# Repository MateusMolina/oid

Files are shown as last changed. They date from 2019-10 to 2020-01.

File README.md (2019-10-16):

# OID | Órteses Inteligentemente Desenvolvidas

Temos o propósito de divulgar de forma open source novos projetos e planos de fabricação de órteses, com foco na qualidade e no custo baixo de fabricação.

## Nossos Projetos

### OID para PTC

- Modelo de órtese
- Tese de bacharelado com roteiro de fabricação

## Membros

- Sérgio Fernando Lajarin
- Mateus Molina

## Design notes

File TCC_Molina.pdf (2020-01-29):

## UNIVERSIDADE FEDERAL DO PARANÁ

SETOR DE TECNOLOGIA

DEPARTAMENTO DE ENGENHARIA MECÂNICA

(DEMEC)

MATEUS MOLINA

ESTUDO COMPARATIVO ENTRE A MANUFATURA ADITIVA E A TERMOFORMAGEM NA FABRICAÇÃO DE ÓRTESES PARA

CRIANÇAS COM PTC

CURITIBA
2019

MATEUS MOLINA

ESTUDO COMPARATIVO ENTRE A MANUFATURA ADITIVA E A TERMOFORMAGEM NA FABRICAÇÃO DE ÓRTESES PARA

CRIANÇAS COM PTC

Monografia apresentada como resultado parcial

à obtenção do grau de engenheiro mecânico,

Curso de Engenharia Mecânica, Setor de

Tecnologia, Universidade Federal do Paraná.

Orientador: Prof. Sérgio Fernando Lajarin

CURITIBA
2019

RESUMO

O pé torto congênito é uma deformidade congênita com incidência de um caso a cada mil nascimentos, a qual é tratada, comumente, de modo não cirúrgico pela utilização de órteses. Ainda não há uma órtese acessível e de qualidade no mercado, o que cria uma oportunidade de estudo para um produto de baixo custo e que, ainda assim, mantenha-se durável e de boa qualidade ao longo da sua vida-útil. Este trabalho busca elucidar as diferenças em custo e parâmetros de qualidade entre órteses fabricadas por meio de dois processos de manufatura, manufatura aditiva e termoformagem com moldes impressos. Produziu-se, para tanto, amostras representativas para cada um dos processos, as quais, posteriormente, foram submetidas a um processo padronizado de teste e obtenção de resultados. Em consideração aos resultados, a termoformagem utilizando PS como material, apresentou melhores resultados em custo de fabricação para o período e estrutura de fabricação definidos, sem deixar de lado os parâmetros de qualidade.

Palavras-chave: Órtese, PTC, Tecnologia Assistiva, Manufatura Aditiva, Termoformagem

LISTA DE ILUSTRAÇÕES

FIGURA 2 - ÓRTESE PARA PTC EM CÓDIGO ABERTO FEITA EM PLA POR IMPRESSÃO

FIGURA 3 - ÓRTESE PRODUZIDA POR AM PARA PACIENTES COM PTC RESIDUAL .... 14

FIGURA 4 – EVOLUÇÃO DO TRATATAMENTO DE PTC NA FASE DE CORREÇÃO COM

FIGURA 10 – REPRESENTAÇÃO ESQUEMÁTICA DE UMA ÚNICA CADEIA POLIMÉRICA

FIGURA 12 - GRÁFICO DO VOLUME ESPECÍFICO EM FUNÇÃO DA TEMPERATURA

PARA TRÊS POLÍMEROS: A (CRISTALINO); B (SEMICRISTALINO); E C (AMORFO) ...... 25

FIGURA 17 - MECANISMO DE EXTRUSÃO GENÉRICO DE UMA IMPRESSORA 3D ........ 34

FIGURA 18 - ESQUEMÁTICO DE UMA PEÇA SENDO IMPRESSA EM 3D CAMADA POR

FIGURA 19 - IMPORTÂNCIA DA ORIENTAÇÃO NA RESISTÊNCIA DA PEÇA IMPRESSA 36

FIGURA 23 - PEÇA DE ABS DEPOIS DE SER TRATADA COM ACETONA (À ESQUERDA)

FIGURA 38 – BASES EM PLA NA ORIENTAÇÃO VERTICAL E HORIZONTAL (À DIREITA)

FIGURA 39 – EQUIPAMENTOS PARA ALISAMENTO SUPERFICIAL COM VAPOR DE

FIGURA 40 – BASE ORIENTAÇÃO VERTICAL EM ABS DEPOIS DO ACABAMENTO ....... 62

FIGURA 42 - MÁQUINA TERMOFORMADORA UTILIZADA PARA A FABRICAÇÃO DA

FIGURA 44 - PLACA E MOLDE POSICIONADOS NA MÁQUINA TERMOFORMADORA .... 67

FIGURA 46 - BASE DA ÓRTESE EM PS RECÉM-RETIRADA DA MÁQUINA

FIGURA 47 - BASE DA ÓRTESE FABRICADA COM EXCESSO DE EMBARRIGAMENTO. 69

FIGURA 48 – MÁQUINA UNIVERSAL DE ENSAIO E POSICIONAMENTO DA ÓRTESE (À

FIGURA 54 – DETALHE DAS MARCAS DE IMPRESSÃO DE UMA BASE IMPRESSA COM

LISTA DE TABELAS

TABELA 6 - FATOR DE AUMENTO RECOMENDADO DO MOLDE PARA DIFERENTES

CONTEÚDO

2.4.3. PLANEJAMENTO DE PROCESSO PARA MANUFATURA ADITIVA........ 37

### 1. INTRODUÇÃO

### 1.1. CONTEXTUALIZAÇÃO

Defeitos e deformidades congênitas são termos usados para descrever os

múltiplos defeitos ósseos e musculares que podem ocorrer durante a gestação. São

geralmente de origem complexa e, em alguns casos, de difícil detecção.

Estima-se que cerca de 2% a 3% dos recém-nascidos são portadores de

alguma deformidade congênita, sendo isso responsável por 20% da mortalidade

neonatal e 30% a 50% da mortalidade perinatal em países desenvolvidos. (CASTRO

et al., 2006)

Dentre as deformidades, o pé torto congênito é uma deformidade congênita

complexa causada pelo desenvolvimento anormal dos ossos, ligamentos e músculos

do bebê enquanto no útero. Essa condição afeta entre 150 a 200 mil recém-nascidos

anualmente em todo mundo. Aproximadamente 80% dessas crianças nascem em

países com baixa renda média. (Global Clubfoot Initiative, 2019)

Essa deformidade é caracterizada por tendões dos pés curtos e tensos, o que

gera a torção do pé para dentro. Se não tratada logo na infância, é muito difícil que a

deformidade se resolva com o tempo. Todavia, a maioria dos casos são tratados com

sucesso por métodos não cirúrgicos, como alongamento, gesso e a utilização de

órteses. Utilizando-se apenas da correção com gessos, os pés tendem voltar à

deformidade. Por isso, é recomendado a utilização das órteses para garantir que os

pés permaneçam na posição correta. Assim, transcorrido um período dependente do

paciente, exige-se a troca da órtese. Esse ciclo repete-se várias vezes ao longo do

tratamento, com duração de uma média 3 anos, utilizando-a de forma integral (23

horas) e reduzindo-a gradualmente para à noite ou durante o sono do dia.

O método supracitado, formulado pelo médico espanhol Ignacio V. Ponseti

(1914-2019), é o mais empregado no tratamento do PTC atualmente, mostrando-se

eficaz quando adotado bem cedo e com o acompanhamento dos pais para que a órtese

seja usada de forma correta (NORDQVIST, 2018). A órtese consiste em dois sapatos,

corretamente angulados, separados por uma barra fixa, assim bloqueando o

movimento entre um pé e outro, como também obstruindo o eixo individual de cada

tornozelo.

FIGURA 1 - ÓRTESE DE DENIS-BROWNE

FONTE: WIKIMEDIA, 2008

### 1.2. FORMULAÇÃO DO PROBLEMA

Com um preço de em média quinhentos reais, a órtese para crianças com pé

torto congênito é de difícil acesso para as muitas famílias que sofrem pela falta de uma

alternativa alcançável. Desse modo, sem o dinheiro necessário para a compra de

órteses, o tratamento acaba sendo retardado ou, até mesmo, não iniciado.

### 1.3. JUSTIFICATIVA

Por existir uma forte demanda por um produto de baixo custo e que consiga

manter boa qualidade, torna-se então fundamental um método de produção satisfatório

para a produção de órteses de forma replicável, eficaz e acessível. Uma opção

facilmente replicável e que possa ser feita em baixa escala, até mesmo localmente,

parte do movimento “faça você mesmo”, contribuiria muito para a acessibilidade do

tratamento.

### 1.4. HIPÓTESE

Tomou-se como hipótese fundamental para o trabalho a possibilidade de

manufatura uma órtese de baixo custo através processos de fabricação acessíveis ao

público comum. Alguns autores já mostraram que é possível, através do uso da

manufatura aditiva, fabricar órteses com custo significativamente menor que o

convencional.

Savone et al. (2019) desenvolveram uma órtese (Figura 2) com código fonte

livre para o tratamento do Pé Torto Congênito (doravante PTC) por meio de manufatura

aditiva, um polímero a baixo custo e acessível como matéria prima. Os resultados

obtidos foram satisfatórios e ultrapassam ou igualam as órteses fabricadas de modo

convencional. O uso de impressão 3D reduziu o custo significativamente e mostrou-se

aplicável em países em desenvolvimento. Neste modelo ainda há certa dificuldade para

a fabricação da barra metálica, devido a geometria e material do mecanismo, o que

mostra que não existe ainda uma solução definitiva para o problema.

FIGURA 2 - ÓRTESE PARA PTC EM CÓDIGO ABERTO FEITA EM PLA POR IMPRESSÃO 3D

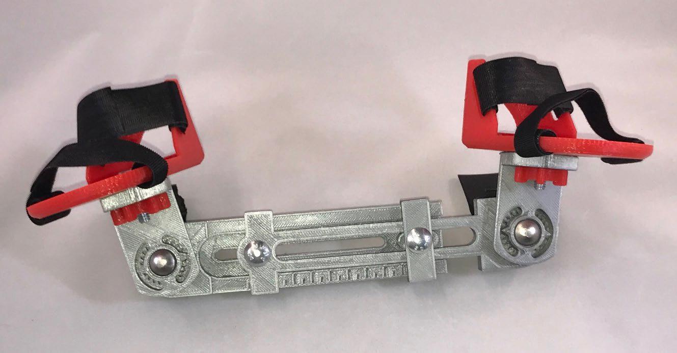
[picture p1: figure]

FONTE: SAVONEN ET AL., 2019

Outrossim, Liu et al. (2014) desenvolveram uma órtese (Figura 3) por

manufatura aditiva por meio de sinterização a laser seletiva para o tratamento de

pacientes com PTC residual. Utilizou-se da tomografia computadorizada e um novo método envolvendo medições de pressões em oito regiões dos pés, enquanto o

paciente andava, para a geração da geometria. Após o uso da órtese, os pacientes

passaram pelo mesmo método de medição a pressões, mostrando uma significativa

melhora na deformidade residual.

FIGURA 3 - ÓRTESE PRODUZIDA POR MANUFATURA ADITIVA PARA PACIENTES COM PTC RESIDUAL

FONTE: LIU ET AL. 2014

### 1.5. OBJETIVO

Projetar e manufaturar órteses para o tratamento de pé torto congênito através

de dois processos de fabricação diferentes, manufatura aditiva e termoformagem,

assim como avaliar seu custo-benefício.

### 2. REVISÃO BIBLIOGRÁFICA

Neste capítulo, primeiramente, são apresentados detalhes do Pé Torto

Congênito e o método de Ponseti, comumente utilizado para o tratamento da condição.

Em seguida, serão discutidas as características dos materiais e dos processos de

fabricação para confecção de órteses.

### 2.1. PÉ TORTO CONGÊNITO

O Pé Torto é uma das deformidades físicas mais comuns, com incidência de

pelo menos um caso a cada 1000 nascimentos. A condição é caracterizada pelo

nascimento de crianças com deformidades na equino no pé, varo do retro pé, cavo do

ante pé e adução do médio e ante pé. (LARA et al., 2013)

Fatores como, predisposição genética, alterações gestacionais e anomalias

histológicas diversas, parecem estar relacionadas ao desenvolvimento da condição.

Entretanto, a sua verdadeira causa permanece desconhecida. (LARA et al., 2013)

Em países desenvolvidos, consegue-se detectar a condição antes ou no

momento do nascimento, assim começa-se o tratamento já no início da infância por

meio de métodos não cirúrgicos. (SAVONEN et al., 2019)

2.1.1. O MÉTODO DE PONSETI

A condição pode ser idiopática e tratada efetivamente por meio do uso do

método de Ponseti logo no início da infância (SAVONEN et al., 2019). O método

desenvolvido por Ponseti, na Universidade de Hospitais e Clínicas de Iowa em 1963,

consistindo em um procedimento de tratamento padronizado e não intrusivo de PTC.

Baseia-se, principalmente, na premissa de que as articulações do tarso não se movem

de forma individual, mas giram em torno de eixos móveis de forma simultânea (DOBBS

et al., 2000). A adequada aplicação do método pode ser dividida em duas fases: a

primeira fase é a correção, envolvendo a utilização de moldes de gessos de forma

seriada; a segunda, a manutenção da correção, utilizando-se usualmente de uma

órtese de abdução – comumente a de Denis-Browne.

Quando corretamente utilizado logo após o nascimento, uma boa condição

clínica pode ser obtida na maioria dos casos. Para a realização dessas condições um

molde de gesso é aplicado semanalmente a fim de reter o grau de correção e amolecer

os ligamentos, como mostrado na Figura 4 (DOBBS et al., 2000). A manipulação e

adequação é usualmente feita pelo uso de uma órtese de abdução do pé. Assim, a

criança deve usar a órtese inicialmente por grande parte do dia (em média 95% desse),

retirando apenas durante o banho pelos primeiros três meses. Nos próximos passos, o

uso segue apenas na hora de dormir ou cochilar, até aos seus quatro anos de idade.

(SAVONEN et al., 2019). Nos dias de hoje, a maior parte dos tratamentos dessa

patologia são iniciados com o emprego desse procedimento pela sua simplicidade,

efetividade e redução drástica das cirurgias extensas. (LARA et al., 2013)

FIGURA 4 – EVOLUÇÃO DO TRATATAMENTO DE PTC NA FASE DE CORREÇÃO COM OS VÁRIOS MOLDES DE GESSOS UTILIZADOS

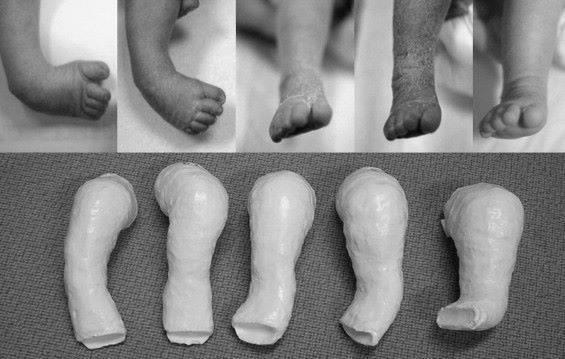
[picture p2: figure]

FONTE: ASSOCIAÇÃO PRIMEIRO PASSO, 2018

Após o tratamento com gesso, que deve ser feito nos primeiros meses de vida,

é indicado o uso da órtese fixa de Denis Browne que tem objetivo de ajudar na correção

dos pés. Para crianças acima de um ano, o uso da órtese de Denis Browne é dificultado

pois traz desconforto e o tratamento continua com o uso de órteses personalizadas suropodálicas (sem a barra metálica entre os pés). Mais detalhes dessas órteses serão

apresentados na sequência.

### 2.2. ÓRTESES

As órteses são dispositivos aplicados externamente para modificar as

características estruturais e funcionais dos sistemas neuromuscular e esquelético. (MINISTÉRIO DA SAÚDE, 2013). Elas atuam de forma complementar ao tratamento

de deformidades não devendo substituí-lo completamente. Além de contribuírem a

reorganização funcional, elas são fundamentais para uma recuperação segura, rápida

e eficaz.

Podem ser confeccionadas com diversos materiais, variando de órteses

metálicas a órteses plásticas e, agora em desuso, madeira. A escolha do material

depende, principalmente, de fatores como o tempo de utilização, a densidade do

material, durabilidade, | porte físico e condições financeiras | do | paciente.

(VASCONCELOS, 2014)

Dividem-se em duas categorias quanto à funcionalidade: órtese estática e

dinâmica. A última proporciona mobilidade articular do paciente associado à atividade

e repouso da articulação. Por outro lado, a órtese estática estabiliza o segmento

deixando em repouso e em posição anatômica funcional, além de favorecer a proteção

do segmento e a prevenção de deformidades. Além disso, as órteses podem ser

confeccionadas sob medida ou pré-fabricada ajustável, o que atenua as limitações

como a espera de confecção e o alto custo. (VASCONCELOS, 2014)

2.2.1. ÓRTESES SUROPODÁLICAS

Segundo o Ministério da Saúde (2013) a fabricação de órteses suropodálicas

ou tornozelo-pé (AFO, do inglês Ankle Foot Orthesis) pode ser feita através do uso de

um molde negativo, molde positivo e, por último, a órtese obtida por termoformagem,

processo esse descrito resumidamente abaixo.

O molde negativo é responsável por extrair as características do membro do

paciente. Normalmente, é feito atando-se com atadura gessada a área na qual deseja-se construir uma órtese. É fundamental a utilização de uma interface entre o paciente e o molde negativo, de modo que possibilite a sua extração futuramente, como é visto

na FIGURA 5.

FIGURA 5 – MOLDE NEGATIVO E O PROCESSO DE REMOÇÃO

FONTE: MINISTÉRIO DA SAÚDE, 2013

O molde positivo é a cópia anatômica do membro com as correções e alívios

necessários. Enche-se o molde negativo de gesso e espera-se a cura por 30 minutos

até que o molde já tenha consistência para ser trabalhado como é visto na FIGURA 6.

Em seguida, é ideal aparar e alisar a superfície do molde com telas extremamente finas

para o adequado acabamento superficial. Ademais, é de boa prática a conferência das

dimensões do molde relativos ao membro do paciente.

FIGURA 6 – MOLDE POSITIVO EM PROCESSO DE CURA

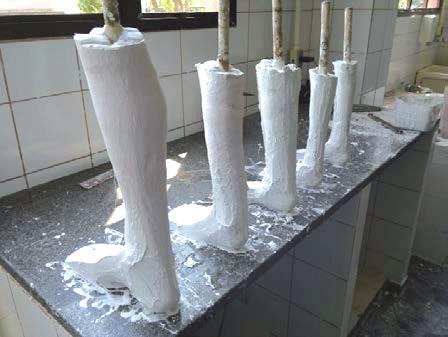
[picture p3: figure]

FONTE: MINISTÉRIO DA SAÚDE, 2013

A próxima etapa do processo, é a moldagem com polipropileno quente. Esse é

aquecido até atingir um estado “borrachoso” que permite a conformação sobre o molde

positivo. Em geral, utilizam-se placas de polipropileno de 3 a 6mm, dependendo do

porte do paciente.

Nesta etapa, o molde positivo é posicionado em uma linha de sucção de alta

vazão com a placa polimérica colocada sobre ele. Com cerca de 165ºC, o polímero

amolece e se torna adequado ao processamento. Por fim, a órtese é retirada do molde

com ajuda de uma serra e está pronta para ajustes de acabamento e remoção de

excesso de material (FIGURA 7).

FIGURA 7 - ÓRTESE RECÉM-MOLDADA

FONTE: MINISTÉRIO DA SAÚDE, 2013

Após o processo de fabricação da órtese, faz-se necessária à sua devida

validação junto ao paciente. Com o auxílio de ferramental mecânico, os cantos vivos

são aparados e os pontos de pressão e desconforto são explicitados pelo paciente

após a colocação da órtese. Esses pontos são, então, devidamente corrigidos. Esse

processo ocorre iterativamente, até que o paciente sinta-se confortável com a órtese.

Em seguida, prossegue-se para o acabamento da órtese, etapa na qual ocorre,

se necessário, ajustes finais de acabamento, a montagem de correias e outros

dispositivos de acessórios para o correto funcionamento e conforto ao usuário. Um

exemplo de órtese para manter o posicionamento tornozelo-pé a 90º, pode ser visto na

FIGURA 8.

FIGURA 8 - ÓRTESE FINALIZADA

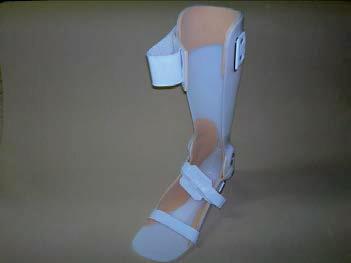
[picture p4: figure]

FONTE: MINISTÉRIO DA SAÚDE, 2013

A órtese suropodálica é amplamente utilizado para tratamento de deformidades

nos membros inferiores, porém em crianças acima de 1 ano de idade. Antes dessa

idade a criança inicia o tratamento com uso do modelo de órtese fixo de Denis Browne.

2.2.2. A ÓRTESE DE DENIS-BROWNE

O modelo de órtese de Denis-Browne que permite manter os membros

inferiores em posições ajustáveis. São feitas geralmente de couro ou polímero, unidas

pelo solado por uma barra metálica que serve para manter os pés na posição desejada

(ver Figura 9).

Segundo Ponseti e Lara et al, após a fase de correção, para a devida

manutenção, é recomendável o uso de uma órtese que trave o movimento dos pés em

torno do eixo do tornozelo em relação um com o outro.

FIGURA 9 – ÓRTESE DE DENIS-BROWNE

FONTE: ASSOCIAÇÃO PRIMEIRO PASSO, 2016

Assim, a órtese deve ser utilizada de forma intensa nos primeiros meses de

vida e gradativamente ter seu uso reduzido para o uso noturno.

Nos primeiros 3 meses o bebê vai usar a órtese em período integral (23 horas

por dia). O médico reduz gradualmente para apenas à noite e durante o sono do dia

(12 a 14 horas por dia). A maioria das crianças deverá usar a órtese por 3 anos.

(PELLEGRINO, 2016)

### 2.3. POLÍMEROS

Os materiais polímeros são componentes integrais da vida cotidiana, e

aparecem desde os artigos domésticos, até em sofisticados aparatos científicos e

instrumentos médicos. Eles oferecem combinações de propriedades físicas e

mecânicas não disponíveis em outros materiais. Vantagens tais como, baixo peso,

resiliência, resistência a corrosão, aderência a cor, transparência e facilidade de

processamento podem ser obtidas com a seleção de um material polimérico.

(CRAWFORD, 1998)

Esses materiais fazem parte do grupo de polímeros que consistem em arranjos

de longas cadeias moleculares. Pertencentes a este grupo estão, também, materiais

naturais como seda, borracha e celulose. No entanto, para chegar a esse resultado, no

século XIX, houve tentativas de sínteses dos materiais poliméricos artificiais, o que

culminou no primeiro sucesso baseado na celulose: o parkesine, criado por Alexander

Parkes, em 1855. Logo percebeu-se a aplicabilidade desse material na indústria, sendo

utilizado, como exemplo, para substituir o marfim na fabricação de bolas de bilhar.

(CRAWFORD, 1998)

Os polímeros consistem em grandes números de cadeias moleculares, cada

uma das quais capaz de dobrar, enrolar e contorcer (Figura 10). Como consequência,

tem-se um emaranhamento das moléculas, o que dá aos polímeros características

singulares e importantes. Esses diferem-se quanto à composição química, tamanho,

forma e estrutura. Quanto à estrutura, os polímeros podem ser amorfos e cristalinos;

possuindo estruturas ordenadas; usualmente opacos; ponto de fusão bem definidos e

pontuais; dotados de alta resistência química, à fadiga e ao desgaste. Aqueles são, de

modo oposto, normalmente transparentes, têm uma faixa de fusão na qual o

amolecimento ocorre gradativamente, e não possuem boa resistência química ou à

fadiga e desgaste. (CALLISTER e RETHWISCH, 2012)

De acordo com a estrutura química da cadeia polimérica, isto é, conforme os

grupos | funcionais | presentes, | os | polímeros | podem | ser | agrupados | em

polihidrocarbonetos, poliamidas, poliésteres, poliéteres, poliacetais, poliuretanos, etc.

(MANO e MENDES, 1999)

FIGURA 10 – REPRESENTAÇÃO ESQUEMÁTICA DE UMA ÚNICA CADEIA POLIMÉRICA

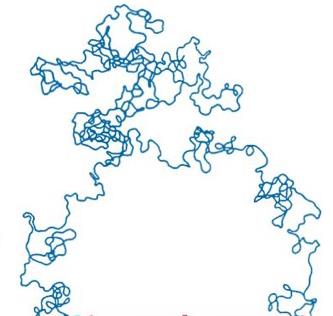
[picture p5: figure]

FONTE: CALLISTER e RETHWISCH, 2012, p. 465

Além disso, é interessante classificá-los quanto à resposta estrutural frente a

uma elevação de temperatura. Nessa classificação, duas categorias são possíveis:

termofixos e termoplásticos. Os termoplásticos amolecem e, eventualmente,

liquefazem com o aumento da temperatura. Os termofixos tornam-se permanentes e

rígidos durante sua formação e não amolecem sob aquecimento. Esses são, em geral,

mais duros e resistentes que os termoplásticos e possuem melhor estabilidade

dimensional. (CALLISTER e RETHWISCH, 2012)

Nota-se que essas aplicações requerem certa resistência mecânica (bolas de

bilhar) e resistência a temperatura (cabo de panela).

Métodos de fabricação como a manufatura aditiva por extrusão utilizam,

comumente, de polímeros termoplásticos como o PLA e o ABS para a produção de

peças de prototipagem rápida com boa estabilidade dimensional e acabamento

superficial. Na Figura 11, vê-se um exemplo de protótipo produzido com uma

impressora 3D utilizando o princípio de extrusão de filamento. O PLA utilizado produziu

um dispositivo com as características desejadas para o projeto: resistência mecânica,

vedação, acabamento superficial e precisão dimensional.

FIGURA 11 - PROTÓTIPO PRODUZIDO COM PLA

FONTE: DO AUTOR

2.3.1. TEMPERATURA DE TRANSIÇÃO VÍTREA

Polímeros cristalinos apresentam apenas temperatura de fusão, ponto acima

no qual o sólido torna-se líquido. Adicionalmente, polímeros amorfos e semicristalinos

apresentam uma transformação gradual de líquido em um material borrachoso e, finalmente, em um sólido rígido durante o resfriamento. A temperatura acima, em que

o material se torna borrachoso, e abaixo, em que o é sólido rígido, é chamada

temperatura de transição vítrea. (CALLISTER e RETHWISCH, 2012)

Durante essa transformação, várias propriedades do polímero são

bruscamente alteradas, tais como rigidez, capacidade calorífica e de expansão térmica.

Essa propriedade está intimamente ligada à definição do processamento dos

polímeros, além de restringir a aplicação por meio de um limite inferior e/ou superior de

temperatura de trabalho. Na Figura 12, pode-se ver um comparativo do impacto no

volume específico de três amostras do material polimérico sob aquecimento. Nota-se

uma visível descontinuidade no comportamento dessa propriedade para o material A,

amorfo, que passa pela transformação vítrea. Esse comportamento não é visto no

polímero C e observado com menor intensidade no polímero semicristalino B.

(CALLISTER e RETHWISCH, 2012)

FIGURA 12 - GRÁFICO DO VOLUME ESPECÍFICO EM FUNÇÃO DA TEMPERATURA PARA TRÊS POLÍMEROS: A (CRISTALINO); B (SEMICRISTALINO); E C (AMORFO)

FONTE: (CALLISTER E RETHWISCH, 2012)

2.3.2. PLÁSTICOS DE INTERESSE

Nos capítulos abaixo serão listadas uma breve descrição das principais

propriedades físicas e mecânicas de aplicações dos plásticos considerados na

execução desse trabalho.

2.3.2.1. POLIETILENO DE ALTA DENSIDADE (PEAD)

O polietileno de alta densidade é um material termoplástico e semicristalino

muito utilizado na indústria por apresentar propriedades físicas e mecânicas

interessantes e pelo seu baixo custo. Esse plástico apresenta boa resistência à

propagação de trincas e performance em alta temperatura e pressão. Como também,

é facilmente adquirido em casas de construção e fornecedores de plástico de

engenharia. (WYPYCH, 2012)

O PEAD é tipicamente processado por injeção, extrusão, moldagem por sopro

e termoformagem. Para este último, deve-se levar em conta sua flexibilidade e,

consequente, “embarrigamento” ao aquecer. As suas principais aplicações na indústria

são a fabricação de tubulações industriais para mineração, distribuição de gás e

produção de gás e óleo. Por outro lado, pode ser encontrado na fabricação de garrafas

de água, embalagens em geral, sacolas próprias para congelador e partes veiculares.

(FORMECH INTERNATIONAL LTD, 2019; WYPYCH, 2012). Na Figura 13, são vistos

exemplos de aplicações do material e, na Tabela 1, encontram-se compiladas

propriedades mecânicas e físicas de interesse desse polímero.

FIGURA 13 - APLICAÇÕES POPULARES DO POLIETILENO

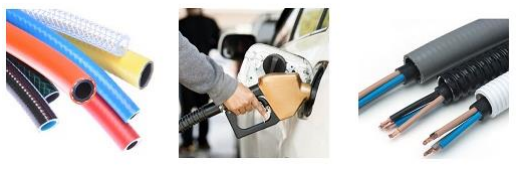
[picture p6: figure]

FONTE: (OMNEXUS, 2019)

TABELA 1 – PROPRIEDADES FÍSICAS E MECÂNICAS DO PEAD

PROPRIEDADE | VALOR
Módulo de Young | 800 Mpa
Limite de Escoamento | 21,4 a 31,0 MPa
Deformação no Escoamento | 8,7 a 15 %

Módulo de Resiliência | 42 KJ m⁻³
Densidade (20ºC) | 0,940 a 0,965 g cm⁻³
Temperatura de Fusão | 125 a 135 ºC
Condutividade Térmica | 0,52 a 0,55 W m⁻¹ K -1
Calor Específico | 1250 J Kg⁻¹ K -1
Temperatura de Transição Vítrea | -118 a -133 ºC
Taxa de Encolhimento | 3 a 3,5%
Temperatura de Orientação | 132 ºC

FONTE: ADAPTADO DE WYPYCH, 2012; FORMECH INTERNATIONAL LTD, 2019; (ENGINEERING TOOLBOX, 2003)

2.3.2.2. POLIESTIRENO (PS)

O poliestireno é um polímero termoplástico amorfo com abundância de sua

utilização na indústria, principalmente devido a sua boa resistência ao impacto e boa

maleabilidade. Possui custo baixo e médio comparado a outros plásticos da

engenharia. (OMNEXUS, 2019)

O PS é tipicamente processado por injeção, extrusão, moldagem por sopro e termoformagem. É principalmente aplicado em componentes eletrotécnicos, itens

domésticos, filme isolante, embalagens e brinquedos (WYPYCH, 2012). Na Figura 14

podem ser vistos exemplos de aplicações do material e, na Tabela 2, tem-se um

compilado das principais propriedades físicas e mecânicas desse polímero.

FIGURA 14 - APLICAÇÕES POPULARES DO POLIESTIRENO

FONTE: OCEAN LEGACY FOUNDATION, 2019

TABELA 2 – PROPRIEDADES FÍSICAS E MECÂNICAS DO PS

PROPRIEDADE | VALOR
Módulo de Young | 3000 a 3500 Mpa
Limite de Escoamento | 23 a 27 MPa
Deformação no Escoamento | 1,6 a 1,8 %
Módulo de Resiliência | 9,6 KJ m⁻³
Densidade (20ºC) | 1,04 a 1,06 g cm⁻³
Temperatura de Fusão | 275 ºC
Temperatura de Amolecimento | 74 ºC
Condutividade Térmica | 0,105 a 0,128 W m⁻¹ K -1
Calor Específico | 1300 J Kg⁻¹ K -1
Temperatura de Transição Vítrea | 85 a 102 ºC
Taxa de Encolhimento | 0,3 a 0,5%
Temperatura de Orientação | 135 ºC

FONTE: ADAPTADO DE WYPYCH, 2012 E FORMECH INTERNATIONAL LTD, 2019

2.3.2.3. POLIPROPILENO (PP)

O polipropileno é um polímero termoplástico semicristalino flexível, com baixa

absorção de umidade e quimicamente inerte. Possui propriedades mecânicas

interessantes como boas resistências ao impacto, todavia com formalidade limitada

devido a sua alta flexibilidade. Possui custo baixo se comparado a outros plásticos da

engenharia. (OMNEXUS, 2019)

O PP é tipicamente processado por injeção, extrusão, moldagem por sopro e

termoformagem. Esse material é muito aplicado pela indústria automotiva, em

componentes elétricos, em fibras, móveis, embalagens, fitas e, até mesmo, bandagens

ortopédicas (WYPYCH, 2012). Na Figura 15, podem ser vistos exemplos de aplicações

do material e, na Tabela 3, tem-se um compilado das principais propriedades físicas e

mecânicas desse polímero.

FIGURA 15 - APLICAÇÕES POPULARES DO POLIPROPILENO

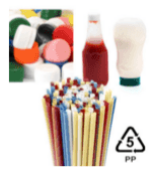
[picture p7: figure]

FONTE: OCEAN LEGACY FOUNDATION, 2019

TABELA 3 – PROPRIEDADES FÍSICAS E MECÂNICAS DO PP

PROPRIEDADE | VALOR
Módulo de Young | 1200 a 2000 Mpa
Limite de Escoamento | 31 a 35,2 MPa
Deformação no Escoamento | 7 a 12 %
Módulo de Resiliência | 34 KJ m⁻³
Densidade (20ºC) | 0,84 a 0,91 g cm⁻³
Temperatura de Fusão | 160 a 176 ºC
Condutividade Térmica | 0,17 a 0,22 W m⁻¹ K -1
Calor Específico | 1920 J Kg⁻¹ K -1
Temperatura de Transição Vítrea | -8 ºC
Taxa de Encolhimento | 1,5 a 2,2%
Temperatura de Orientação | 138 ºC

FONTE: ADAPTADO DE WYPYCH, 2012; FORMECH INTERNATIONAL LTD, 2019; ENGINEERING TOOLBOX, 2003

2.3.2.4. POLIÁCIDO LÁCTICO (PLA)

O PLA é um bioplástico termoplástico biodegradável semicristalino, muito

utilizado em impressoras 3D para produção de protótipos com bom nível de

detalhamento. Esse plástico é diferente de outros polímeros por ser derivado de recursos renováveis como a cana de açúcar e amido de milho. Além disso, possui

características físicas e mecânicas similares a materiais como PP e PE (Rogers, 2015).

FIGURA 17 - APLICAÇÕES DO PLA: PARAFUSO MÉDICO

FONTE: ROGERS, 2015

Devido à natureza do processo, pode ocorrer divergências de propriedades na

impressão 3D, culminando em peças com comportamento tipicamente anisotrópico. A

tabela 4 apresenta um compilado das principais propriedades físicas e mecânicas deste

polímero

TABELA 4 – PROPRIEDADES FÍSICAS E MECÂNICAS DO PLA

PROPRIEDADE | VALOR
Módulo de Young | 3700 a 4100 Mpa
Limite de Escoamento | 65,6 a 77 MPa
Deformação no Escoamento | 2,4 a 10 %
Módulo de Resiliência | 65 KJ m⁻³
Densidade (20ºC) | 1,21 a 1,29 g cm⁻³
Calor Específico | 540 a 600 J K⁻¹ Kg⁻¹
Temperatura de Fusão | 164 a 178 ºC
Temperatura de Transição Vítrea | 55 a 75 ºC

FONTE: ADAPTADO DE WYPYCH, 2012

O PLA é tipicamente processado por injeção, extrusão e impressão 3D. Esse

material aplicado com frequência pela indústria na fabricação de filamentos. Há

comunidades de impressão 3D online, nelas designers de vários países disponibilizam

seus trabalhos, possibilitando a impressão de peças à qualquer pessoa que possua

impressora 3D (WYPYCH, 2012)

TABELA 4 – PROPRIEDADES FÍSICAS E MECÂNICAS DO PLA

PROPRIEDADE | VALOR
Módulo de Young | 3700 a 4100 Mpa
Limite de Escoamento | 65,6 a 77 MPa
Deformação no Escoamento | 2,4 a 10 %
Módulo de Resiliência | 65 KJ m⁻³
Densidade (20ºC) | 1,21 a 1,29 g cm⁻³
Calor Específico | 540 a 600 J K⁻¹ Kg⁻¹
Temperatura de Fusão | 164 a 178 ºC
Temperatura de Transição Vítrea | 55 a 75 ºC

FONTE: ADAPTADO DE WYPYCH, 2012

2.3.2.5. ACRILONITRILA BUTADIENO ESTIRENO (ABS)

O ABS é um polímero termoplástico e amorfo muito utilizado em conjunto com

processos de injeção e impressoras 3D para produção de protótipos funcionais.

Apresenta propriedades interessantes para indústria, como boa resistência mecânica

e tenacidade e resistência à corrosão. (Rogers, 2015)

Esse plástico é tipicamente processado e fundido, por injeção, moldagem

rotacional, extrusão e impressão 3D. O material é muito aplicado pela indústria na

fabricação de filamentos para impressoras 3D, utensílios domésticos, painéis

automotivos, partes de portas, partes de computador, mobília, equipamento de

jardinagem, brinquedos e embalagens. Na Figura 16, podem ser vistos exemplos de

aplicações do material e, na Tabela 5, tem-se um compilado das principais

propriedades físicas e mecânicas deste polímero.

FIGURA 16 – APLICAÇÕES POPULARES DO ABS

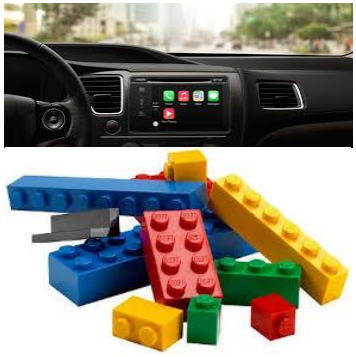
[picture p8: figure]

FONTE: ROGERS, 2015

TABELA 5 – PROPRIEDADES FÍSICAS E MECÂNICAS DO ABS

PROPRIEDADE | VALOR
Módulo de Young | 1208 a 1939 Mpa
Limite de Escoamento | 35 a 58 MPa
Deformação no Escoamento | 2,4 a 4 %
Módulo de Resiliência | 69 KJ m⁻³
Densidade (20ºC) | 1,03 a 1,09 g cm⁻³
Temperatura de Fusão | 220 a 260 ºC
Condutividade Térmica | 0,16 W m⁻¹ K -1
Calor Específico | 1780 a 2030 J K⁻¹ Kg⁻¹
Temperatura de Transição Vítrea | 102 a 107 ºC
Temperatura de Orientação | 138 ºC

FONTE: ADAPTADO DE WYPYCH, 2012; FORMECH INTERNATIONAL LTD, 2019

### 2.4. MANUFATURA ADITIVA

Manufatura aditiva é um processo de fabricação que tem como característica a

deposição sucessiva de material na forma de camadas. Ela possui diversas tecnologias

diferentes que são aplicadas nas mais diversas áreas, tais como engenharia, medicina,

educação, arquitetura, cartografia, brinquedos e entretenimento (ISO/ASTM, 2015)

Esse método de fabricação é conhecido por produzir representações de

sistemas e partes de forma rápida antes do lançamento e comercialização do produto.

Logo, tem-se um protótipo ou modelo base como resultado nos quais futuros modelos

e, possivelmente, o sistema final, serão derivados. (GIBSON, ROSEN e STUCKER,

2015)

De acordo com a norma ISO/ASTM 52900:2015, esse processo de fabricação

é dividido em sete princípios distintos:

1. Binder jetting: princípio no qual um agente ligante líquido é depositado

seletivamente para ligar pó material;

2. Directed energy deposition: princípio no qual energia térmica focalizada é

usada para unir materiais por fusão no momento da deposição;

3. Material extrusion: princípio no qual material é seletivamente depositado por

meio de um bico ou orifício;

4. Material jetting: princípio no qual gotículas de material são depositadas

seletivamente

5. Powder bed fusion: princípio no qual a energia térmica é seletivamente aplicada

para unir regiões de uma camada de pó material;

6. Sheet lamination: princípio no qual camadas de material são unidas com solda

ultrassônica ou por meio de papel adesivo;

7. Vat photopolymerization: princípio no qual líquido foto-polimerizante é utilizado

em conjunto com luz ultravioleta, aplicada seletivamente para construir um

objeto físico.

Devido ao baixo custo, simplicidade e disponibilidade das tecnologias de

extrusão de material esse é o princípio amplamente utilizado e por essa razão será

mais amplamente revisado na seção seguinte.

2.4.1. PRINCÍPIO DE EXTRUSÃO DE MATERIAL

Atualmente, o método mais comum de prototipagem rápida é a impressão 3D

baseada na extrusão de material. Ele utiliza de modelos CAD para a produção

de objetos físicos de forma ágil e que não necessitam de elevada resistência

mecânica. O mecanismo de funcionamento é o de extrusão do material

polimérico termoplástico em camadas finas, orientadas por um arquivo SML, que

define as coordenadas de extrusão para a impressora. Na FIGURA 17, encontra-

se um esquemático do funcionamento de uma impressora 3D genérica.

Primeiramente, o material polimérico é desenrolado por meio de motores

elétricos em direção ao bico ao qual é aquecido um pouco acima de sua

temperatura de fusão. Assim, o material é depositado no lugar correto com um

conjunto de servo motores capazes de mover o conjunto extrusor nas três

dimensões necessárias. (LIOU, 2008)

FIGURA 17 - MECANISMO DE EXTRUSÃO GENÉRICO DE UMA IMPRESSORA 3D

FONTE: ADAPTADO DE LIOU, 2008

A impressão é realizada camada por camada, com o bico extrusor movendo-

se nas direções horizontais e transversais, adequando-se à altura para a impressão da

próxima camada, como se vê na figura 21. Esse método de impressão apresenta

algumas limitações nas geometrias complexas, as quais não se tem apoio entre uma

camada e outra em ângulos mais agudos. Desse modo, faz-se necessário a utilização

de geometria de suporte para fornecer o devido apoio entre camadas. Essa geometria adicional vem com o ônus de aumento de gasto com material e perda de acabamento

superficial.

FIGURA 18 - ESQUEMÁTICO DE UMA PEÇA SENDO IMPRESSA EM 3D CAMADA POR CAMADA

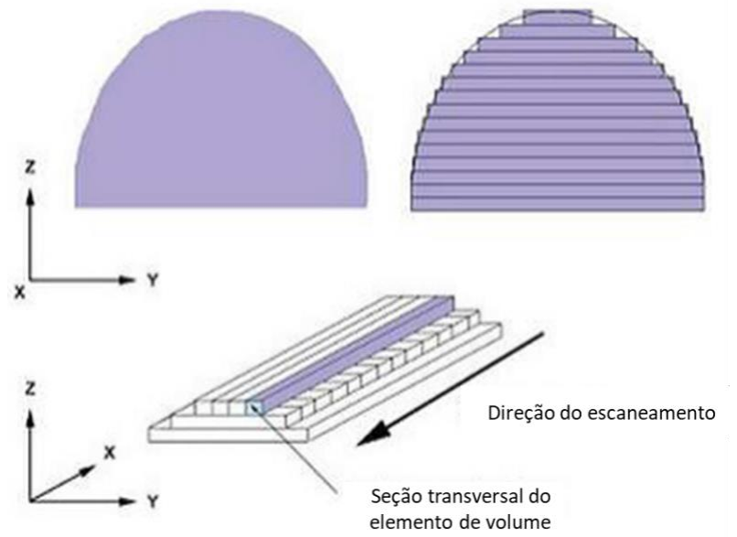
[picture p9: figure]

FONTE: CANESSA, FONDA E ZENNARO (2013)

Essa ferramenta é utilizada em praticamente todas as indústrias: automotivas,

aeroespaciais, negócios, máquinas comerciais, médica etc. A agilidade ganhada na

fabricação, a utilização de materiais não tóxicos, capacidade de operar em um

ambiente de escritório e o não desperdício de matéria prima, fazem desse processo

um recurso valioso de prototipagem e teste.

A técnica da modelagem tridimensional permite a realização de projetos

personalizados de produtos, o que facilita no atendimento das necessidades de cada

cliente individualmente, tanto no que diz respeito às especificações, quanto a design

inovador e utilização de uma variedade de materiais para a fabricação. (HAUSMAN e

HORNE, 2014) (MIETTI e VENDRAMETO, 2000)

Ainda de acordo com Horne e Hausman (2014), uma vantagem muito

significativa é a produção de estruturas complexas, rígidas e leves, que seriam

impossíveis de serem fabricadas por processos de moldagem e fundição. Assim, as

impressões 3D podem produzir objetos leves, o que reduz custos, como por exemplo,

economia de combustível, utilização de menos material para deposição e aplicação de

materiais alternativos e mais baratos, como os de origem vegetal para o molde das

peças.

A prototipagem rápida permite a reciclagem das peças, pois o protótipo não é

enviado ao cliente final, podendo voltar a sua condição original para possíveis

alterações, o que, além de reduzir os custos, diminui o impacto ambiental, pois evita

descarte de peças e permite o aproveitamento de materiais usados para a fabricação

de novos protótipos (MIETTI e VENDRAMETO, 2000). No que diz respeito ao processo

de produção, permite a produção em pequenas escalas, em menor tempo, utilizando

menos material e mão-de-obra do que a produção em massa tradicional. (MIETTI e

VENDRAMETO, 2000).

2.4.2. ORIENTAÇÃO DA PEÇA NA PLATAFORMA DE IMPRESSÃO

Variando-se a orientação da peça, ou seja, como ela é a impressa, tem-se uma

grande mudança no tempo de impressão, na precisão e na resistência geral da peça.

Isso deve-se à característica anisotrópica do processo de impressão 3D por extrusão,

visto que a ligação do material depositado consecutivamente em uma mesma camada

e entre camadas são de naturezas diferentes, essa apresentando vãos entre camadas,

até mesmo, a completa não adesão entre partes de uma camada e outra. (REDWOOD,

2019)

Na Figura 19 é ilustrada a importância de definir corretamente a orientação da

peça antes de realizar a impressão. Uma peça sujeita a tensão horizontal, impressa

também de maneira horizontal, tenderá a romper por cisalhamento entre as camadas.

Deste modo, recomenda-se a impressão de modo que a tensão esteja paralela às

camadas, resultando em uma peça muito mais resistente.

FIGURA 19 - IMPORTÂNCIA DA ORIENTAÇÃO NA RESISTÊNCIA DA PEÇA IMPRESSA

FONTE: ADAPTADO DE REDWOOD, 2019

A fim de se obter um ótimo acabamento, recomenda-se imprimir a peça de

modo que contornos complexos estejam dentro de uma só camada. Isso é atingido

quando se orienta, por exemplo, na construção de um cilindro, a peça no sentido axial.

Caso o cilindro seja impresso deitado, há uma aproximação da superfície da peça em

retângulos, gerando uma peça com pior acabamento, como pode ser visto Figura 20.

FIGURA 20 - INFLUÊNCIA DA ORIENTAÇÃO NO ACABAMENTO SUPERFICIAL

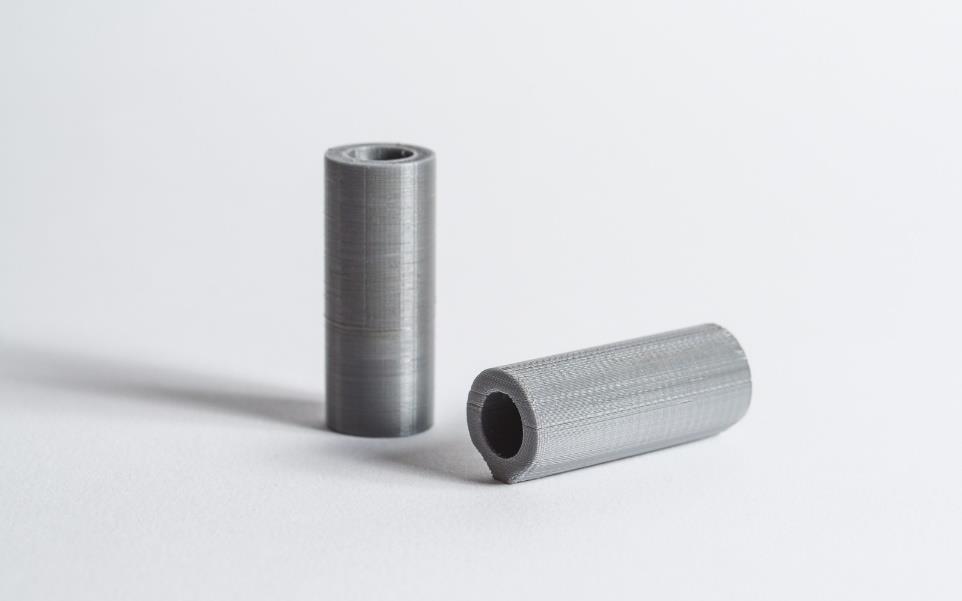
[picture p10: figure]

FONTE: REDWOOD, 2019

2.4.3. PLANEJAMENTO DE PROCESSO PARA MANUFATURA ADITIVA

Segundo Volpato (2017), recomenda-se que o processo de desenvolvimento

de produto envolvendo uma máquina de manufatura aditiva passe por etapas como

ilustradas na FIGURA 21.

FIGURA 21 - ETAPAS DO PLANEJAMENTO DE PROCESSO PARA AM.

FONTE: ADAPTADO DE VOLPATO, 2017

A primeira etapa consiste na obtenção de modelo geométrico 3D do produto a

ser fabricado. Esse, comumente, é obtido por meio de softwares CAD que permitem o

desenho tridimensional de partes e montagens. Outro meio eficaz, é a utilização de

scanners 3D que possibilitam a leitura, interpretação e conversão para um objeto virtual

3D de objetos físicos. (GIBSON, ROSEN e STUCKER, 2015)

Em sequência, o modelo deve ser convertido a um formato STL (acrônimo para

STereoLithograhy). Com o uso desse formato, tem-se uma maneira simplificada de se

representar a geometria singularmente. Para tanto, a geometria é convertida em uma

série de triângulos superficiais que, em geral, dever ser menor que a resolução da

impressora 3D utilizada. (GIBSON, ROSEN e STUCKER, 2015)

Desse modo, o STL é importado no software que faz a interface entre o modelo

virtual e a impressora 3D. Essa ferramenta, em geral, é responsável por fatiar o modelo

de acordo com os parâmetros especificados, isto é, cortar a peça em camadas

assimiláveis pela máquina, e, quando necessário, adicionar estruturas de suporte à

peça.

No evento pode possuir áreas sem apoio e características desconectadas uma

das outras, assim, faz-se necessário a utilização de estruturas de suporte. Essas são

divididas quanto ao material utilizado, podendo ser do mesmo tipo do material que será

manipulado na impressão da peça ou de um material secundário. Assim, terá como

vantagem a possibilidade de ter um outro material com características secundárias

desejáveis para materiais de suporte. Um exemplo comum é a utilização de materiais solúveis em água, os quais podem ser, após a impressão, facilmente removidos. Em

decorrência disso, ter-se-á um melhor acabamento superficial na peça.

Na Figura 22, vê-se um caso típico, o qual é necessário o uso de estrutura de

suporte. Essa surge para corrigir a falta de apoio presente quando o ângulo entre

camadas é muito acentuado.

FIGURA 22 - EXEMPLO DE PEÇA COM ESTRUTURA DE SUPORTE

FONTE: ANDREW CRAIGIE, 2012

Com a peça e os suportes fatiados, o modelo então é parametrizado e obtém

o contorno a ser seguido pelo extrusor em cada camada. O software de controle deve

também determinar como melhor preencher o material entre os contornos. Essa etapa

é crucial, pois o extrusor deposita fisicamente o material que preenche um espaço

outrora vazio. Para evitar que não haja adesão entre o material e a mesa, ou material

previamente depositado, deve-se assegurar que seja depositado suficientemente

próximo à camada adjacente. (GIBSON, ROSEN e STUCKER, 2015)Assim que essas

etapas estejam concluídas, o processo muda para a fase de construção controlada por

computador. Nesse, a sequência de comandos originada do software anterior é

repassada à máquina de impressão, a qual se encarregará de converter código em

movimento de translado do extrusor e, efetivamente, de extrusão e retração de material

polimérico. Assim, o processo será repetido camada por camada até que a peça seja

concluída.

Após a remoção das estruturas do suporte, a fim de se obter melhores

resultados de acabamento superficial, recomenda-se a aplicação de técnicas de pós-

processamento de plásticos, podendo envolver desde o lixamento da superfície do

material, polimento até tratamentos químicos, como a utilização de vapor de acetona

em polímeros do tipo ABS (GIBSON, ROSEN e STUCKER, 2015). Na Figura 23, vê-se

um exemplo de aplicação estética desse tipo de pós processamento

FIGURA 23 - PEÇA DE ABS DEPOIS DE SER TRATADA COM ACETONA (À ESQUERDA)

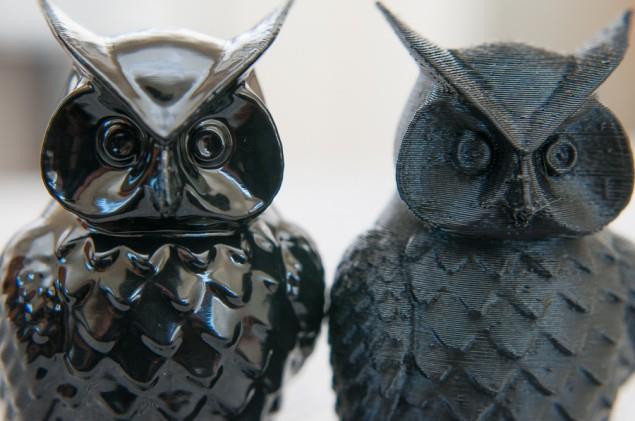
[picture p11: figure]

FONTE: SINKHACKS, 2019

### 2.5. TERMOFORMAGEM

O processo de termoformagem consiste no aquecimento de uma chapa

termoplástica até a sua temperatura vítrea de amolecimento. Posteriormente ocorre a

conformação por meios mecânicos, pressão de ar comprimido, vácuo ou

simultaneamente mais de um destes processos (Figura 24). Esse método apresentava

restrições. Por exemplo, a distribuição irregular de plástico na parede da peça e gasto

excessivo de material nas periferias. Este aspecto limita a aplicação em embalagens

simples. Com avanços tecnológicos, em meados da década de 1950 ocorreram

melhorias que ampliaram a aplicação em bacias para geladeira, para-choque de carros

e painéis de interruptor. (CRAWFORD, 1998).

FIGURA 24 - ESQUEMÁTICO DE UM PROCESSO DE TERMOFORMAGEM

FONTE: ADAPTADO DE LEITE, RUBIO, ET AL., 2018

As principais categorias da termoformagem, segundo Crawford são a

moldagem a vácuo e moldagem à pressão. Chanda e Roy (2007) incluem uma terceira

categoria, que utiliza de moldes macho e fêmea pressionados um contra o outro com

a lâmina plástica entre eles, a moldagem mecânica. A moldagem a vácuo consiste no

aquecimento de um polímero termoplástico e na sua moldagem pela redução da

pressão de ar entre ele e o molde. Chamado de moldagem negativa, esse consiste no

uso de uma lâmina de plástico de espessura entre 0,025 e 6,5 mm fixa sobre o molde

aberto. Um sistema de aquecimento, então, amolece a lâmina até um ponto definido e,

em seguida, aplica-se o vácuo. A diferença de pressão entre o ar atmosférico e o vácuo

gerado garante a moldagem do plástico. De modo semelhante, tem-se o método da

moldagem positiva, no qual um molde positivo (macho) é empurrado contra a lâmina

de plástico. Esse último garante melhor distribuição de material e é capaz de produzir

formas mais profundas. (CRAWFORD, 1998)

A moldagem à pressão utiliza, de modo semelhante à modelagem a vácuo, um

aquecedor para amolecer o plástico e a lâmina plástica sobre o molde. Todavia, nesse

processo utiliza-se de ar comprimido para moldar a lâmina plástica, o qual é aplicado

na parte superior da lâmina. Se comparado com a moldagem a vácuo, essa técnica

permite ciclos mais rápidos de produção, melhor qualidade superficial e controle

dimensional da peça. (CHANDA e ROY, 2007)

Uma gama de materiais pode ser utilizada com esse método de fabricação.

Polímeros como Poliestireno, ABS, PVC, acrílico, policarbonato, polipropileno e

polietileno de baixa e alta densidade são aplicados com frequência e produzem

resultados satisfatórios quanto a propriedades mecânicas. (CRAWFORD, 1998)

2.5.1. TERMOFORMAGEM A VÁCUO

Como introduzido no subcapítulo 1.1, esse processo envolve o aquecimento

de uma chapa plástica que é comprimida contra um molde, enquanto o vácuo é

aplicado. Em seguida, por meio de um sistema de ar com direção revertida ou

manualmente, a peça finalizada é extraída do equipamento.

O processo apresenta vantagens como as condições baixas pressões de te

moldagem, a possibilidade de uso de moldes de baixo custo e fabricados com materiais

não custosos. Em contrapartida, há perda de material ao redor do molde, já que se faz

necessária uma chapa com área maior que a área efetiva moldada. (FORMECH

INTERNATIONAL LTD, 2019)

Na Figura 25, são resumidas as etapas típicas para a correta execução do

processo de termoformagem a vácuo. Adicionalmente, abaixo dessa é feito uma breve

explicação de cada etapa baseada nos dados divulgado por Formtech International

LTD (2019).

FIGURA 25 - PASSOS TÍPICOS PARA A TERMOFORMAGEM A VÁCUO

FONTE: ADAPATADO DE FORMTECH INTERNATIONAL LTD, 2019

a) Travamento | b) Aquecimento | c) Nivelamento

a) Travamento: o mecanismo de travamento deve ser suficientemente poderoso

para travar a chapa mais espessa a ser utilizada na máquina.

b) Aquecimento: os aquecedores são geralmente elementos infravermelho montados em uma placa refletora de alumínio. É essencial para a correta

execução do processo um aquecimento uniforme de toda a placa do material

polimérico. Pirômetros são geralmente utilizadas para a verificação e controle

da temperatura do processo de termoformagem.

c) Nivelamento da Chapa: opcionalmente, a fim de aumentar o controle do

processo, procura-se evitar que a chapa de plástico sofra o efeito de

embarrigamento ao ser aquecida. Para este fim, utiliza-se um pequeno fluxo

de ar injetada na cavidade de baixo da máquina contra a placa, logo

levantamento a chapa.

d) Pré-estiramento: assim que o plástico atinge a temperatura correta de

moldagem, este pode ser pré-estirado para assegurar uniformidade de

espessura de parede. Esta etapa é essencial para a moldagem de peças com

alta profundidade com ângulos mínimos e alto nível de detalhamento superficial

do molde.

e) Aplicação do Vácuo: após toda a sequência de etapas, uma bomba de palheta

é usada para se extrair o ar preso entre a chapa e o molde.

f) Contramolde auxiliar: a fim de se obter ainda melhores resultados de

uniformidade de espessura de parede e maleabilidade de peças profundas,

além de minimizar defeitos comuns na termoformagem, pode-se utilizar um

contramolde acima da área de moldagem. Atuado por um cilindro hidráulico ou

pneumático, o contramolde é pressionado contra a chapa polimérica, assim

melhorando a precisão dimensional e qualidade do processo.

g) Resfriamento e Extração: depois da peça ser termoformada, deve-se aguardar

seu devido resfriamento antes de ser extraída. Pode-se, em adição, utilizar de

ventiladores e sprays de névoa para diminuir o tempo de espera.

2.5.2. FABRICAÇÃO DE MOLDES PARA TERMOFORMAGEM

Os moldes possuem várias funções dentro do processo de termoformagem. A

mais importante é que é ele que define a geometria da peça, além disso é que, a partir

dele, pode-se variar a textura da peça, adicionar logos e outros detalhes. O molde,

ainda, age como um trocador de calor, removendo calor da peça e facilitando o

processo de resfriamento.

Eles devem ser robustos o suficiente para produzir o número de peças para o

qual foram projetados. Ademais, precisam ter adequado fluxo de ar para evacuar o

espaço entre a chapa aquecida e a superfície do molde durante o processo de

termoformagem. (KLEIN, 2009)

Segundo Klein (2009) o projeto de moldes deve seguir as seguintes

considerações: escolha do material do molde, geometria do molde, ventilação

Materiais podem ser categorizados e adequados para produção de peças de

baixo ou alto volume. Moldes para baixo volume são vantajosos quando é necessário

personalização, rapidez e baixo custo de produção. Exemplos de moldes nessa

categoria são os moldes feitos a partir de madeira, espuma sintética, gesso, plástico.

A principal desvantagem desses materiais é a baixa condutividade térmica, o que

dificulta o resfriamento adequado da peça. O material mais utilizado para altos volumes

de produção é o Alumínio, que apresenta alta resistência e altíssima condutividade

térmica.

A geometria do molde também é um fator importante para a correta execução

do processo de termoformagem. Ela deve seguir recomendações de valores de raio de

canto, ângulo de saída, além de permitir a contração característica, oriunda do

aquecimento e resfriamento de materiais. Uma prática comum é aumentar o tamanho

do molde por um fator, com base no material escolhido para termoformagem. Na

Tabela 6, encontram-se valores típicos do fator de aumento do molde para diferentes

materiais.

TABELA 6 - FATOR DE AUMENTO RECOMENDADO DO MOLDE PARA DIFERENTES MATERIAIS
Material plástico | Fator de Aumento do Molde
PEAD | 0,017 – 0,022
PET | 0,007
PP | 0,017
PS | 0,005
PVC | 0,004

FONTE: KLEIN, 2009

Todos os moldes devem apresentar maneiras de permitir a passagem do ar

entre a chapa aquecida e o molde. Desse modo, é prática comum adicionar respiros

no molde, cuja função é facilitar a moldagem da chapa e a acelerar o contato desta

com a superfície do molde. O tamanho desses respiros deve ser suficiente pequeno

para que o material não seja puxado para dentro dos furos, mas grande o suficiente

para permitir a exaustão do ar rapidamente. O diâmetro dos respiros recomendável é

altamente dependente do material a ser termoformado e de sua espessura, podendo

variar de 0,076 a 1mm. Um exemplo de molde que utiliza respiros para facilitar o fluxo

de ar é visto na Figura 26.

FIGURA 26 - MOLDE COM RESPIROS PARA FACILITAR O FLUXO DE AR

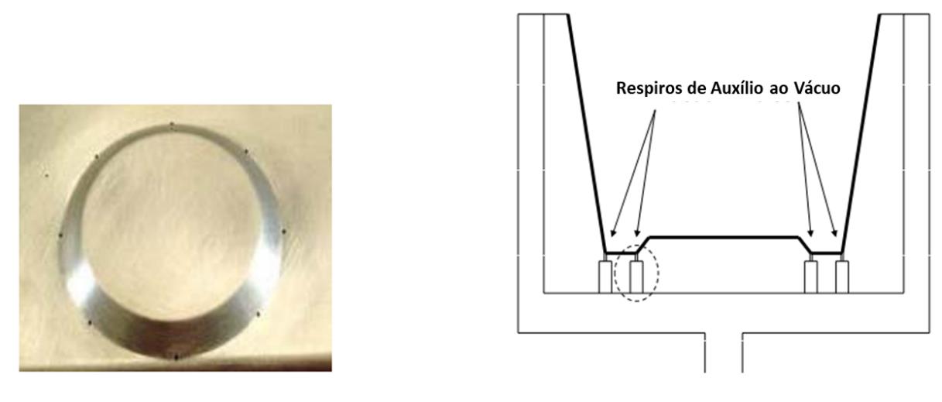
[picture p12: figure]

FONTE: ADAPTADO DE KLEIN, 2009

Assim como os moldes para injeção de polímeros, para altos volumes de peças

é recomendável adequado controle de temperatura do molde. Esse pode ser feito por

meio de fluxo de água interno ao molde que passa primeiro por um controle de

temperatura, logo aquecendo ou resfriando o molde como desejado.

### 3. METODOLOGIA E PLANEJAMENTO EXPERIMENTAL

Com objetivo fabricar e analisar o custo benefício de órteses fabricadas por

diferentes processos de fabricação foi estabelecido um fluxograma de trabalho, como

ilustrado na Figura 27. O trabalho foi estruturado com a sequência planejamento,

execução para cada processo de fabricação e compilação de resultados.

FIGURA 27 - FLUXOGRAMA DE PLANEJAMENTO E EXECUÇÃO DOS TESTES

FONTE: DO AUTOR

### 3.1. PREPARAÇÃO

3.1.1. DEFINIÇÃO DO PROBLEMA E A METODOLOGIA

Neste trabalho será estudado a fabricação de um modelo de órtese fixa de

Denis-Browne, com projeto adaptado com objetivo de reduzir custo. Para facilitar o

entendimento da órtese, ela foi dividida em quatro componentes, como ilustrado na

figura 33:

FIGURA 28 - DIAGRAMA DOS COMPONENTES DA ÓRTESE

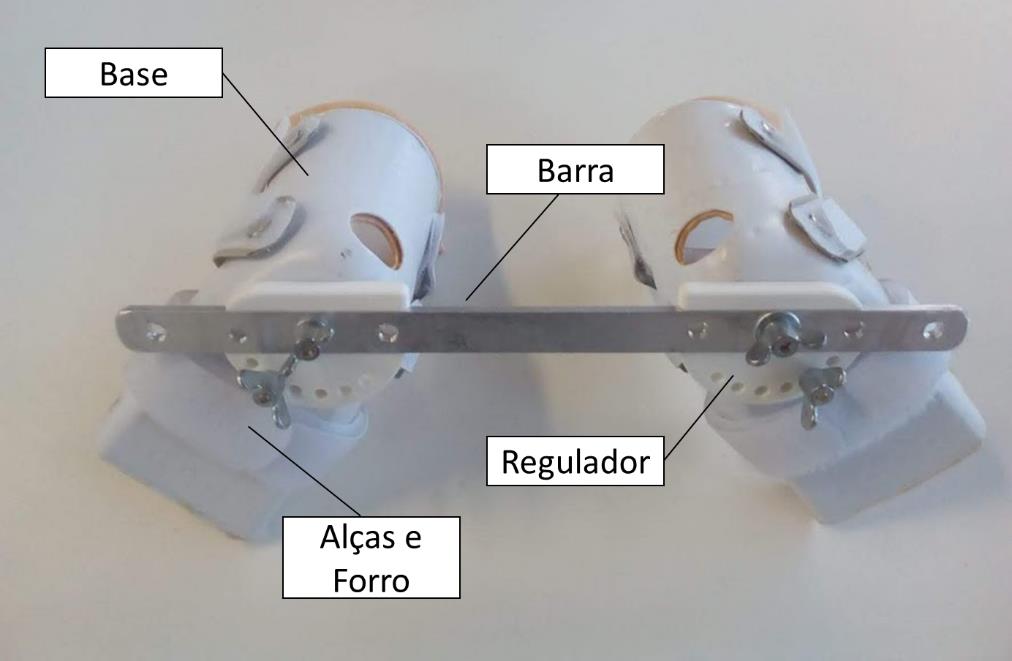
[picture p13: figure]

FONTE: DO AUTOR

3.1.2. DEFINIÇÃO DE REQUISITOS DE CLIENTE E ENGENHARIA

A fim de nortear a avaliação dos diferentes materiais e processos de

fabricação, elaborou-se, com base em entrevistas com os clientes secundários e

terciários, uma lista de requisitos de cliente para uma órtese para PTC. As entrevistas

foram, então, resumidas na tabela 7 – tabela 7 com um grau de importância de 1 a 9,

respectivamente. Gradativamente, um requisito de grau 1 é pouco relevante, enquanto

que o grau 9 apresenta altíssima relevância.

TABELA 7 – REQUISITOS DO CLIENTE
REQUISÍTO DO CLIENTE | IMPORTÂNCIA (1-9)
Órtese confortável e que permita uso prolongado | 9
Órtese Resistente | 9
Preço baixo | 9
Produto leve | 6
Não aqueça muito em meio a clima quente | 3
Produto customizável | 3
Rápida entrega | 6

FONTE: DO AUTOR

Em sequência, na Figura 29, foram definidos quais requisitos de engenharia

eram de consideração necessária para a fabricação da órtese. Para cada requisito

buscou-se definir um valor alvo, com base na pesquisa feita em Referências

Bibliográficas. Os modelos mais comuns de Denis Browne têm o calçado de couro e

amarras de cadarços. Com objetivo de propor um projeto alternativo, ele foi baseado

nas talas suropodálicas personalizadas feitas em PP. Para esse modelo, o Ministério

da Saúde (2013) recomenda a utilização de polipropileno termoformado. Juntando-se

a isso, atualmente, segundo Ministério da Saúde (2013), o método convencional de

fabricação de órteses para membros inferiores recomenda a utilização de polipropileno

termoformado. Logo, foi adotado os valores das propriedades físicas e mecânicas

desse polímero como valor alvo para os requisitos de projeto. Os blocos em azul

destacam esses valores para cada requisito.

Com o propósito de assegurar a robustez do produto, utilizou-se como

premissa fundamental, a resposta mecânica somente na região linear do diagrama

tensão-deformação, ou seja, sem que ocorra escoamento. Nesse sentido, a métrica

para resistência mecânica foi a tensão de escoamento, e, pelo mesmo princípio, para

métrica para tenacidade, o módulo de resiliência.

FIGURA 29 -- REQUISITOS DE ENGENHARIA E VALORES ALVO EM AZUL

FONTE: DO AUTOR

Com o intuito de verificar o impacto de cada um dos requisitos funcionais na

qualidade final do produto, utilizou-se da matriz QFD (Quality Function Deployment)

para relacionar e ponderar requisitos funcionais e de cliente (Figura 30). A ferramenta

é importante, pois traduz as vontades dos clientes, normalmente genéricas, em

características mensuráveis. Dela, obtém-se uma lista priorizada de requisitos

## Órtese

Tensão de
Escoamento

Módulo de
Resiliência

Processabilidade

Densidade

Calor específico

Custo | R$ 100

funcionais que devem ser levados em conta na seleção do material e do processo do

projeto. (ROZENFELD et al., 2006)

FIGURA 30 - QFD DO PROJETO

FONTE: DO AUTOR

A matriz deixa claro a importância na correta seleção do material da órtese para

atender as expectativas do paciente. Propriedades como, resistência mecânica,

tenacidade e densidade, devem ser analisadas de cada material cogitado, pois

interferem diretamente na robustez e no conforto geral da órtese.

Além disso, dois fatores de alta importância para os clientes aparecem em

destaque nos requisitos do projeto, o custo da fabricação e a densidade. Estes fatores

são determinantes para o projeto, pois definem o conforto e a acessibilidade do

produto.

Assim, levando em conta as características supracitadas e a facilidade de

fabricação, recomenda-se um material da família dos plásticos, os quais têm bom

histórico de aplicação na fabricação de órteses. Em sequência, com base em Wypych

(2012), foi elaborada e disponibilizada nas Referências Bibliográficas do trabalho em Direção de Melhoria | ↑ | ↑ | ↑ | ↓ | ↑ | ↓

Importância
| Requisitos Funcionais Requisitos do Cliente________________
9 | Órtese confortável e que permita uso prolongado
9 | Órtese Robusta
9 | Preço baixo
6 | Produto leve
3 | Não aqueça muito em meio a clima quente
3 | Produto customizável
6 | Rápida entrega

Limite de Escoamento
Módulo de Resiliência

Processabilidade

Densidade

Calor específico Custo

Pontuação de Importância | 162 | 189 | 90 | 126 | 117 | 135
Importância relativa | 20% | 23% | 11% | 15% | 14% | 16%
Prioridade | 2 | 1 | 6 | 4 | 5 | 3
Correlação: | Forte | Média | Fraca | Nenhuma

2.3.2 uma compilação de informações importantes de plásticos que possam atender as

especificações do projeto. De modo que, a seleção foi feita a partir do ferramental e

maquinário disponível na universidade para a fabricação do projeto, além de critérios

como disponibilidade, processabilidade e custo do material, definiu-se, na Figura 31,

os plásticos a serem estudados e com qual(is) processo(s) de manufatura ocorreria o

teste.

FIGURA 31 - MATERIAIS E PROCESSOS TESTADOS NO PROJETO

FONTE: DO AUTOR

3.1.3. COMPONENTES E MODELO DA ÓRTESE

Foi adotada uma geometria padrão para a órtese, para que a comparação entre

os materiais e processos sejam simplificados e confiáveis. Esta geometria baseia-se

em modelos de órteses de Denis-Browne, disponíveis para pacientes de até 5 meses

do mercado, servindo como base para possíveis melhorias futuras.

Por conseguinte, a órtese foi modelada em um projeto do professor doutor

Sérgio Fernando Lajarin, do departamento de Engenharia Mecânica da UFPR, o qual

simplifica a fabricação de órteses para pé torto congênito. Para a realização da

modelagem, foi utilizado o software CAD Autodesk Fusion 360 (AUTODESK, 2019)

com licença para estudante.

Como descrito em 3.1.1 a órtese foi dividida em 4 partes, base, barra, alças e

forro e regulador. A base da órtese é o componente responsável por restringir o

movimento do pé como parte do método de Ponseti para tratamento de PTC. Como

este componente apresenta geometria complexa e está diretamente em contato com o

paciente, é essencial a utilização de um processo de fabricação capaz de aliar precisão

Manufatura Aditiva

PLA

ABS

Termoformagem

PE

PP

PS dimensional e resistência mecânica. Para isso, o modelo utilizado, como visto na

(figura 32, a), tem apoio para a sola do pé e tornozelo e, portanto, deve ser utilizado

junto com alças para manter um bom suporte ao pé do paciente. Para tal, existem furos

para rebites nas laterais da geometria.

Ademais, os dois furos na sola têm função de fixação da base no regulador e,

com isso, permitir o travamento em relação à barra. Por outro lado, o furo de diâmetro

maior presente no tornozelo é relevante para o médico acompanhar a posição do

calcanhar relativo à base da órtese.

A barra, como visto na 8 (figura 32, b), serve como travamento do movimento

de um pé em relação ao outro. Ela deve permanecer rígida, ser leve e possibilitar o

ajuste conforme o paciente. Assim sendo, o material escolhido foi o alumínio e optou-

se por ajustes por meio de furos, os quais o conjunto base da órtese e regulador é

fixado.

A alça (figura 32, c) deve permitir o ajuste da órtese em cada paciente. Dessa

forma, optou-se por um conjunto costurado de tecido e velcro, o primeiro realizando a

função do componente e o segundo atuando como interface entre o paciente e o velcro,

gerando conforto ao usuário.

Esse componente é, em seguida, montado na órtese por meio de uma argola

impressa em PLA (figura 32, d) que, por sua vez, é fixada em um pedaço de velcro

rebitado direto nos furos laterais da base da órtese.

A interface entre o usuário e a base da órtese é dada pelo forro, o qual é

colocado diretamente na sua superfície interna. Para isso, o material escolhido foi o

EVA pela disponibilidade e pelo fato de ser vastamente utilizado pela indústria como

material de palmilha de tênis.

O regulador, visto na figura 32 (e), tem como função ajustar o ângulo entre o

eixo horizontal da barra e do tornozelo. Assim, o componente é fixado entre a barra e

a base da órtese por meio de parafusos. Por conseguinte, a peça apresentou boa

resistência e função quando fabricada por manufatura aditiva com PLA.

A órtese completa pode ser vista na figura 32 (f). A órtese da foto foi construída,

com exceção dos fixadores, alça, barra e forro, por meio de manufatura aditiva.

A órtese e o roteiro de fabricação estão disponibilizados no formato livre pela

licença GNU General Public License v3 (FREE SOFTWARE FOUNDATION, 2007) e

pode ser utilizada e melhorada gratuitamente por qualquer pessoa que queira fabricar

sua própria órtese de Denis-Browne desde que mantenha o código livre.

FIGURA 32 – COMPONENTES DA ÓRTESE

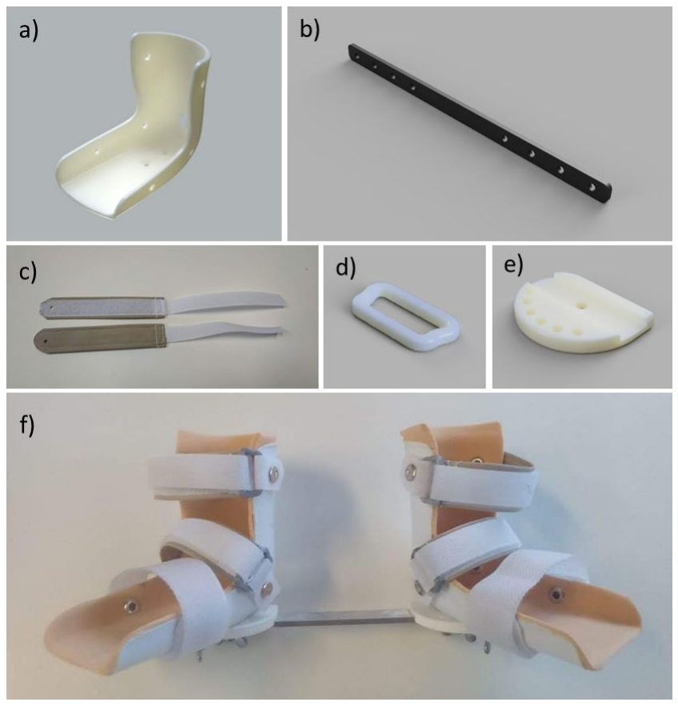
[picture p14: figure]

FONTE: DO AUTOR

### 3.2. FABRICAÇÃO DA BASE DA ÓRTESE

3.2.1. MANUFATURA ADITIVA

Para este processo serão abordados o processo construtivo de órteses por

impressão 3D via extrusão de filamento. Primeiramente, tem-se uma visão geral de

como o procedimento experimental foi planejado, seguido pelo processo construtivo e

o pós-processamento das bases impressas.

3.2.1.1. PLANEJAMENTO DO PROCESSO

O processo foi adaptado de Volpato (2017), e consistiu em 4 etapas principais:

planejamento, calibração e parâmetros de impressão, fabricação e acabamento.

FIGURA 33 - ROTEIRO DE TESTE PARA TERMOFORMAGEM

FONTE: DO AUTOR

O intuito da etapa do planejamento é listar os testes realizados e selecionar

quais materiais e ferramentas foram utilizados. Além disso, buscou-se verificar qual

orientação de impressão resulta na maior resistência mecânica à peça final, como a

necessidade de suporte em cada caso de impressão.

Na etapa de calibração, buscou-se definir ótimos parâmetros de impressão

para obter uma peça que não tenha defeitos de manufatura, com bom acabamento e

boa resistência.

Para a fabricação, buscou-se mostrar o processo de fabricação da base da

órtese, tanto para PLA, como ABS nas orientações consideradas. Este envolveu a

conversão da geometria ao formato STL, definição de parâmetros de suporte e

estruturais, seguido pela conversão desse para um GCODE e, efetivamente, a

impressão da peça. Após a fabricação, adotou-se, de acordo com o material de

processamento, métodos diferentes de acabamento.

Na Tabela 8, são encontrados os materiais utilizados, bem como as

especificações dos rolos de filamento.

TABELA 8 - MATERIAIS UTILIZADOS PARA IMPRESSÃO 3D

Material | Marca | Especificação
PLA | Material3D | Espessura 1,75mm/1kg
ABS | Material3D | Espessura 1,75mm/1kg

FONTE: DO AUTOR

A impressora 3D utilizada para o trabalho foi da Creality modelo Ender-3, cujo

dados técnicos encontram-se compilados na Tabela 9.

TABELA 9 - DADOS TÉCNICOS DA IMPRESSORA 3D

Parâmetro | Valor
Marca/Modelo | Creality Ender-3
Área útil de impressão | 220x220x250 mm
Potência Máxima | 360 W
Potência na Impressão | 120 W
Diâmetro do Filamento | 1,75 mm
Resolução | 0,05 mm
Diâmetro do Bico | 0,4 mm

FONTE: CREALITY, 2019

FIGURA 34 - IMPRESSORA 3D UTILIZADA PARA O TRABALHO

FONTE: DO AUTOR

A fim de se verificar a influência do material e orientação na resistência da

peça, optou-se por comparar quatro bases diferentes em material e/ou orientação,

como visto na Tabela 10.

TABELA 10 - MATERIAIS UTILIZADOS PARA IMPRESSÃO 3D

Material | Orientação
PLA | Vertical
PLA | Horizontal
ABS | Vertical
ABS | Horizontal

FONTE: DO AUTOR

Como também, optou-se por duas orientações diferentes com base no descrito

por Redwood (2019). A orientação é de suma importância para a garantia de resistência

mecânica da peça. Peças impressas com a direção de impressão das camadas,

coincidindo com a direção do carregamento em uso, apresentando bem menos

resistências que as impressas em direção perpedincular.

Chama-se de peças com orientação vertical, as bases impressas em uma peça

só, com a base fixa na mesa impressão, como visto na Figura 35. Pela natureza do

processo, nesta orientação há menor resistência mecânica no apoio do calcanhar.

Todavia, a impressão é mais rápida e não é necessária nenhuma etapa extra de

colagem.

FIGURA 35 - BASE DA ÓRTESE IMPRESSA NA ORIENTAÇÃO VERTICAL

FONTE: DO AUTOR

Para testar a influência, optou-se pela impressão também na orientação

horizontal (Figura 36), isto é, com a premissa que a tensão não atuaria com

cisalhamento entre camadas no apoio do calcanhar, embora comprometendo a

resistência na mesma direção da impressão. Essa orientação, teoricamente, aumenta

a resistência mecânica nos locais tipicamente frágeis da órtese, a custo de maior

consumo de material, tempo de impressão e para retirada de suporte.

FIGURA 36 - BASE DA ÓRTESE NA ORIENTAÇÃO HORIZONTAL

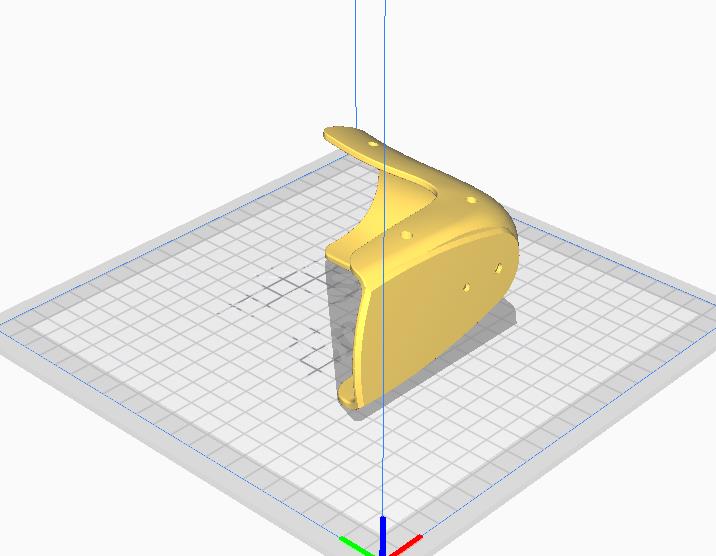
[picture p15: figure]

FONTE: DO AUTOR

3.2.1.2. ROTEIRO DE FABRICAÇÃO DA BASE DA ÓRTESE

As impressoras 3D trabalham com um arquivo no formato GCODE, o qual

armazena informações de coordenadas e parâmetros de impressão ao longo do

processo de impressão. A obtenção desse arquivo se dá, comumente, por meio de um

software Slicer, o qual é capaz de converter um arquivo STL (do inglês

stereolithography) em um formato interpretável pela impressora.

O arquivo STL pode ser gerado por um modelo e software CAD dotado de

função de exportação para STL. Como esclarecido no capítulo 3.1.3, a geometria da

base da órtese foi modelada com o software Autodesk Fusion 360 e o mesmo software foi utilizado para exportar o arquivo para STL, por meio da operação “Export...”,

disponível dentro do menu “File”, como mostrado na Figura 37.

FIGURA 37 - CAIXA DE DIÁLOGO PARA EXPORTAÇÃO DO ARQUIVO PARA STL

FONTE: DO AUTOR

Com o arquivo gerado, utilizou-se do software Ultimaker Cura 4.3

(ULTIMAKER, 2019), um Slicer open-source amplamente utilizado. O software trabalha

com diferentes parâmetros de impressão, os quais devem ser ajustados de acordo com

o modelo, necessidade e impressora do usuário para obtenção de um resultado ótimo.

Para cada conjunto material e orientação, utilizou-se um conjunto diferente de

parâmetros, como listados na Tabela 11. Estes parâmetros foram obtidos por meio de

testes anteriores e foram considerados ótimos para a continuação do trabalho. A

orientação é expressa por “V” como vertical e “H”, horizontal.

TABELA 11 - PARÂMETROS DE IMPRESSÃO

PLA | ABS
Cat. | Parâmetro | V | H | V | H | Uni. Geral
Velocidade de Impressão | 50 | 50 | 50 | 50 | mm/s
Temperatura do bico | 200 | 200 | 235 | 235 | ºC
Temperatura da mesa | 55 | 55 | 110 | 110 | ºC
Velocidade de Retração | 50 | 50 | 50 | 50 | mm/s
Distância de Retração | 2,0 | 2,0 | 2,0 | 2,0 | mm
Espessura da camada | 0,20 | 0,20 | 0,20 | 0,20 | mm
Camadas na base | 3 | 3 | 3 | 3 | -
Camadas no topo | 3 | 3 | 3 | 3 | -
Camadas na parede | 3 | 3 | 3 | 3 | -
Preenchimento | 20 | 20 | 20 | 20 | %
Geometria do Preenchimento | Cross | | | | -
Ãngulo de Overhang | 45 | 45 | 45 | 45 | º
Densidade do Suporte | - | 15 | - | 15 | %
Distância z da interface | - | 0,2 | - | 0,2 | mm
Densidade da Interface | - | 85 | - | 85 | %

Infill

Suporte

FONTE: DO AUTOR

Com o sistema CAM devidamente configurado, a funcionalidade “Slice” foi

utilizada, a qual converte o modelo 3D em uma série de comandos no formato GCODE.

Os arquivos foram então salvos em um cartão MicroSD. O cartão foi, então, inserido

na impressora para realizar a impressão.

O processo de impressão foi bem-sucedido para cada um dos arquivos, o que

resultou em peças, quando necessário, com suporte de fácil remoção e bom

acabamento superficial, desconsiderando a distinção entre camadas da impressão 3D

por extrusão de filamento. Na Figura 38, são mostradas as bases impressas em PLA

na orientação vertical e horizontal (à direita) recém retiradas da plataforma.

FIGURA 38 – BASES EM PLA NA ORIENTAÇÃO VERTICAL E HORIZONTAL (À DIREITA)

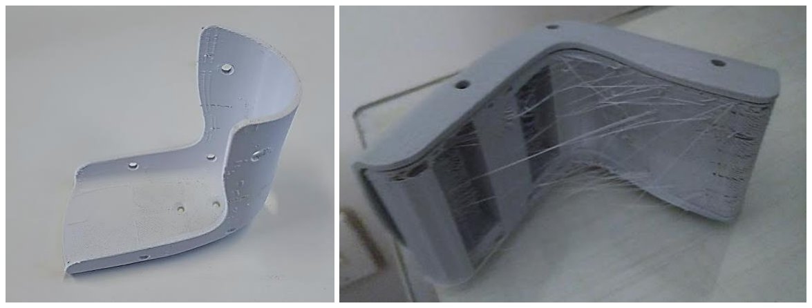
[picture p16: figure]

FONTE: DO AUTOR

As bases impressas horizontalmente demoraram e consumiram mais que o

dobro relativo às bases impressas verticalmente, isso devido ao uso de suportes para

a correta impressão.

3.2.1.3. ACABAMENTO

Após a impressão e remoção dos suportes das peças impressas, obtém-se,

em geral, uma superfície com camadas visíveis e com baixa qualidade nos locais onde

foi necessário suporte, efeito esse mais aparente nas bases impressas na orientação

horizontal. Desse modo, o acabamento é uma etapa importante para melhorar a

qualidade da superfície e diminuir a anisotropia, melhorando a resistência da peça.

(ARMSTRONG, 2019)

Segundo Armstrong (2019), pode-se melhorar a superfície de uma peça

impressa com PLA por meio de um sucessivo lixamento da superfície, com lixas de

granulometria cada vez maior. As bases impressas em PLA horizontal foram lixadas

com lixas de granulometria 220, 400, 600, 1000 e 2000, tomando-se cuidado para lixar

em movimentos circulares e sem rapidez para não se gerar muito calor e danificar a

superfície.

Para as peças impressas em ABS, optou-se pelo tratamento da superfície com

vapor de acetona, à qual o plástico é, de fato, solúvel. O vapor de acetona é muito

eficaz em retirar as marcas de camada de peças produzidas com ABS, deixando a

peça com um aspecto liso e brilhante.

Para o processo de acabamento, foi utilizado acetona, papel toalha e um

recipiente plástico não solúvel em acetona, como visto na Figura 39. Primeiro foram fixadas folhas de papel toalha nas laterais internas do recipiente plástico, as quais

foram, em seguida, embebidas com acetona. A peça, então, foi colocada dentro do

recipiente, o qual foi tampado a fim de impedir a saída do vapor de acetona. Foram

tomados os devidos cuidados no manejo de instalações com vapor de acetona, sendo

usado luva e máscara para a não contaminação do organismo do manuseador.

FIGURA 39 – EQUIPAMENTOS PARA ALISAMENTO SUPERFICIAL COM VAPOR DE ACETONA

FONTE: DO AUTOR

Após, aproximadamente, 15 minutos, verificou-se que a peça estava com bom

acabamento, através de inspeção visual. O resultado pode ser visto na Figura 40.

FIGURA 40 – BASE ORIENTAÇÃO VERTICAL EM ABS DEPOIS DO ACABAMENTO

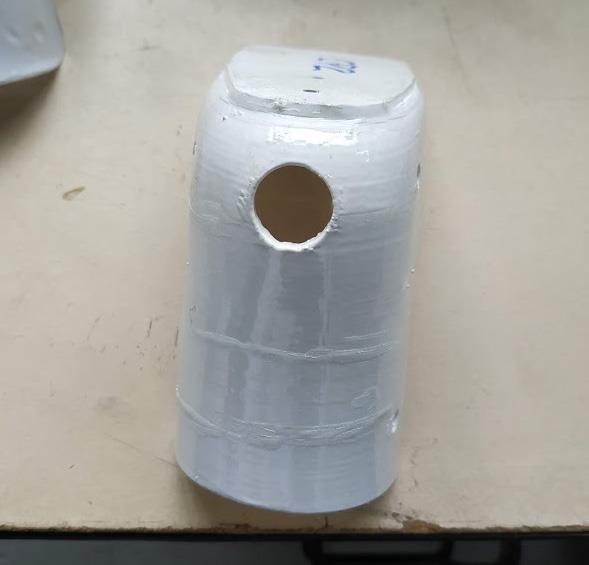
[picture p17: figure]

FONTE: DO AUTOR

Comparativamente, o PLA apresentou pior acabamento superficial justamente

pela falta de um método fácil e não perigoso de processamento da superfície. O ABS

revelou-se de fácil e rápido acabamento, produzindo peças com superfície lisa e com

pouca distinção entre camadas.

3.2.2. TERMOFORMAGEM

Para este processo, serão abordados o método construtivo de órteses por

termoformagem com a utilização de impressão 3D para a fabricação do molde.

Primeiramente, tem-se uma visão geral de como o procedimento experimental foi

planejado, seguido pelo processo construtivo do molde impresso e a fabricação da

órtese.

3.2.2.1. PLANEJAMENTO DO PROCESSO

O experimento foi dividido em quatro etapas, como visto no diagrama abaixo.

FIGURA 41 - ROTEIRO DE TESTE PARA TERMOFORMAGEM

FONTE: DO AUTOR

Para a etapa de fabricação da base da órtese, utilizou-se, como guia, a apostila

prática de termoformagem de Formech International LTD (2019) e dados técnicos do

fabricante da termoformadora.

Como especificado na seção 3.1, foram testados os seguintes materiais para

confecção das órteses: PP, PE, PS. Dados relativos ao material, espessura e preço,

encontram-se resumidos na Tabela 12. Os materiais foram comprados em Curitiba, em

lojas de plásticos para engenharia.

TABELA 12 - RESUMO DOS MATERIAIS UTILIZADOS PARA TERMOFORMAGEM
Material | Espessura
PS | 2.0 mm
PP | 2.0 mm
PE | 2.0 mm

FONTE: DO AUTOR

Durante o processo, foram cronometrados o tempo de processamento de cada

teste realizado e procurou-se definir padrões de teste para melhorar a repetibilidade do

processo.

Para a fabricação, utilizou-se uma termoformadora e uma impressora 3D para

a fabricação das órteses e do molde, respectivamente.

O molde foi modelado por meio do software CAD (computer aided design) e

fabricado em uma impressora 3D com o filamento PLA.

Para o processamento da base da órtese, utilizou-se uma termoformadora à

vácuo da marca FlockColor, cujo dados técnicos encontram-se compilados na Tabela

13 e sua imagem, na Figura 42.

TABELA 13 - DADOS TÉCNICOS DA TERMOFORMADORA

Parâmetro | Valor
Marca | FlockColor
Modelo | Compacta Média
Área útil de processamento | 410x410mm
Altura máxima de moldagem | 140mm
Espessura Máxima do Material | 2mm
Potência | 3000W

FONTE: FLOCKCOLOR, 2019

FIGURA 42 - MÁQUINA TERMOFORMADORA UTILIZADA PARA A FABRICAÇÃO DA ÓRTESE

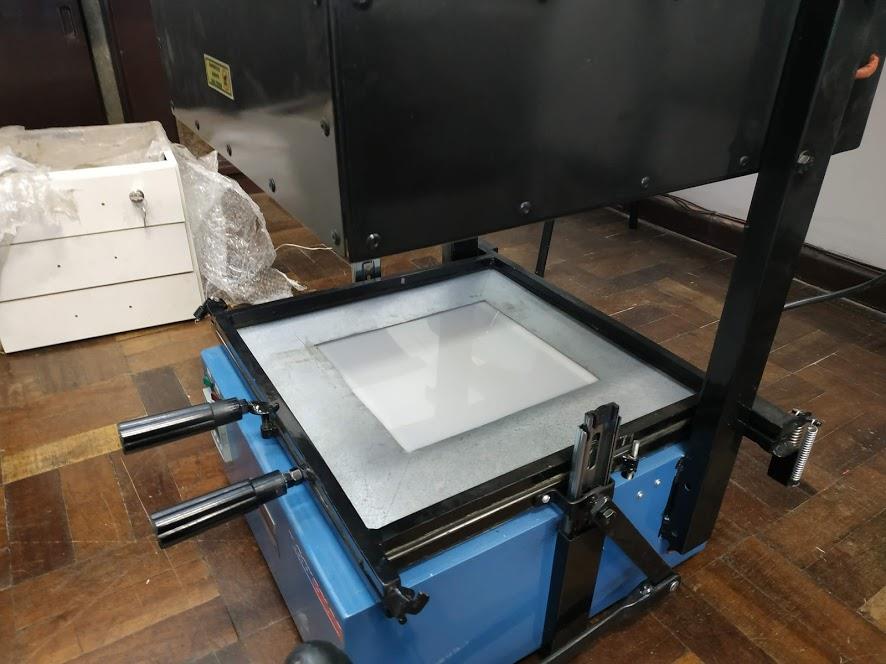
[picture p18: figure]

FONTE: DO AUTOR

A impressora 3D utilizada foi a Creality Ender-3, especificada com maiores

detalhes na seção de fabricação na base da órtese via Manufatura Aditiva deste

trabalho.

Por fim, foi detalhado o processo de acabamento na base da órtese recém-

saída da termoformadora até a peça aparada e em condição final.

3.2.2.2. MODELAGEM E FABRICAÇÃO DO MOLDE

De acordo com Klein (2009), o molde serve como definidor da geometria da

peça a ser termoformada e é diretamente responsável por definir o tempo de

resfriamento, textura e nível de detalhamento da peça final.

Adotou-se como premissa para o trabalho, a fabricação de um baixo volume

de órteses customizáveis e de baixo custo. Sendo assim, optou-se por um material

capaz de facilitar o teste de diferentes moldes e permitir a rápida produção deles. O

material escolhido foi o PLA, que pode ser facilmente impresso pela maioria das

impressoras 3D disponíveis no mercado.

Como pode ser visto na Figura 43, o molde utilizou de respiros para facilitar o

fluxo de ar e melhorar a qualidade da moldagem. Além disso, o molde seguiu os valores

recomendáveis de ângulo de saída e raio de canto conforme especificado por Klein,

2009.

FIGURA 43 – MOLDE UTILIZADO PRODUZIDO EM PLA

FONTE: DO AUTOR

O molde foi utilizado com materiais como o PE, PP e PS com grande sucesso,

sem deformação após o fim do processo e produzindo peças com bom acabamento

superficial e nível de detalhes. No entanto, devido à baixa condutividade térmica do

material e ausência de controle de temperatura, constatou-se alto tempo de

resfriamento, por volta de 10 minutos, para em seguida retirar a peça e produzir uma

nova base.

Assim como a órtese, o molde encontra-se disponível de forma livre sob licença

GNU v3, sendo assim, permitido acesso livre e modificações à peça original.

3.2.2.3. ROTEIRO DE FABRICAÇÃO DA BASE DA ÓRTESE

O procedimento experimental de termoformagem foi executado conforme

descrito em Formech Internetional LTD (2019).

A chapa de material polimérico foi, primeiramente, comprada em Curitiba e

cortada de acordo com a especificação do maquinário. Em testes preliminares,

constatou-se que uma espessura mínima de 2,0 mm é necessária para a correta aplicação. Em testes com PS, de espessura 1,5 mm, verificou-se deformação

excessiva, o que é inadequado para uso prolongado.

Em seguida, ajustou-se corretamente a placa na parte de cima da máquina

termoformadora e foi colocado o molde na parte de baixo como ilustrado na Figura 44.

FIGURA 44 - PLACA E MOLDE POSICIONADOS NA MÁQUINA TERMOFORMADORA

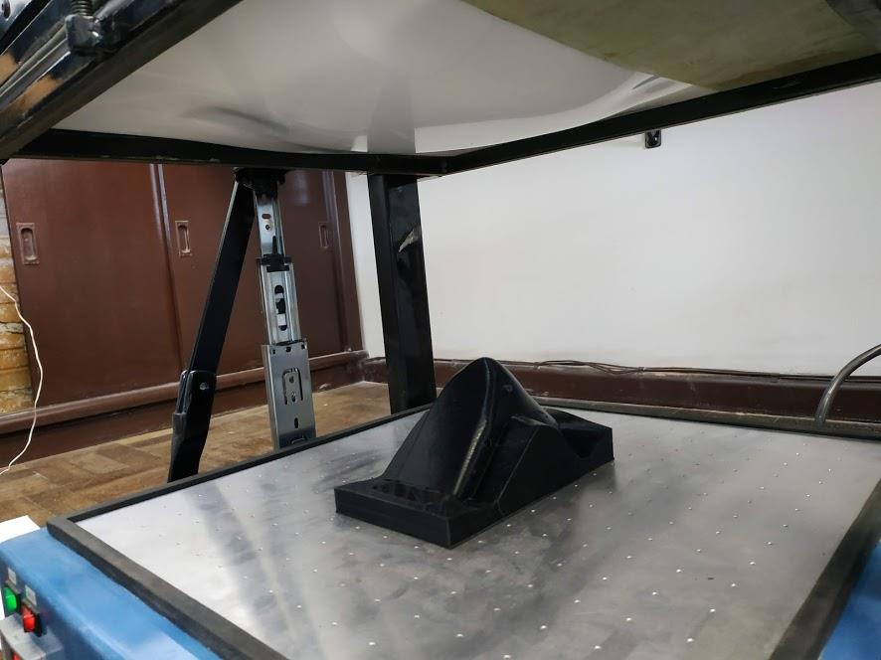
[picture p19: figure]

FONTE: DO AUTOR

A fim de definir uma boa repetibilidade do processo, foi utilizado, inicialmente,

um pirômetro para medir a temperatura da chapa plástica ao longo do processamento.

Todavia, devido à sensibilidade do dispositivo frente à emissividade do objeto a ser

medido e a não conformidade deste para chapas de PP, PE e PS, não se obteve os

resultados fiéis à realidade. Dessarte, optou-se pela inspeção visual como método de

verificar se a chapa está pronta para ser termoformada. Este método é, muitas vezes,

recomendado pela literatura para pequenas escalas. (FORMECH INTERNATIONAL

LTD, 2019).

O PP e o PE apresentaram, no aquecimento, um comportamento similar,

provando-se facilmente inspecionado o ponto de termoformagem do material. Ao longo

do aquecimento, são criadas nervuras ao longo da superfície da chapa, além de

começar a “embarrigar”, isto é, deformar em sentido à gravidade. Em seguida, o

plástico de cor branca utilizado começa a tornar-se transparente e, quando toda a superfície em contato com o aquecedor torna transparente e novamente lisa, tem-se o

ponto ideal de processamento com base nos experimentos. O processo é ilustrado na

Figura 45.

FIGURA 45 - ETAPAS DA TERMOFORMAGEM DO PP E PE

FONTE: DO AUTOR

Esses materiais, em especial o PE, ainda apresentaram alta contração, o que

explicita a necessidade de ajustar-se o molde de acordo com a necessidade. Para além

disso, o PP mostrou-se pior em aderir o formato do molde, produzindo, relativo aos

outros materiais testados, uma base com pior definição de geometria. Com o PS

observou-se um comportamento diferente. Apesar deste apresentar, também,

“embarrigamento”, não é percebido alteração de cor ou transparência na superfície

polimérica. Um bom indicador do ponto correto de termoformagem, foi o comprimento

da deformação da chapa medida sentido gravidade da base da chapa até o ponto de

maior deformação. Para uma espessura de 2,0 mm da chapa, foi constatado que,

quando esse comprimento alcança aproximadamente 30 mm, há boa aderência de forma no molde e não há defeitos superficiais perceptíveis, como é possível ver o

resultado na Figura 46.

FIGURA 46 - BASE DA ÓRTESE EM PS RECÉM-RETIRADA DA MÁQUINA TERMOFORMADORA

FONTE: DO AUTOR

Ao se termoformar antes do ponto ótimo, ou seja, com pouco

“embarrigamento”, não há aderência da chapa à forma do molde. Ao passo que, um

comprimento muito superior, é relacionado com pior qualidade superficial e o

aparecimento de nervuras ao longo da chapa termoformada, como é possível ver na

Figura 47.

FIGURA 47 - BASE DA ÓRTESE FABRICADA COM EXCESSO DE EMBARRIGAMENTO

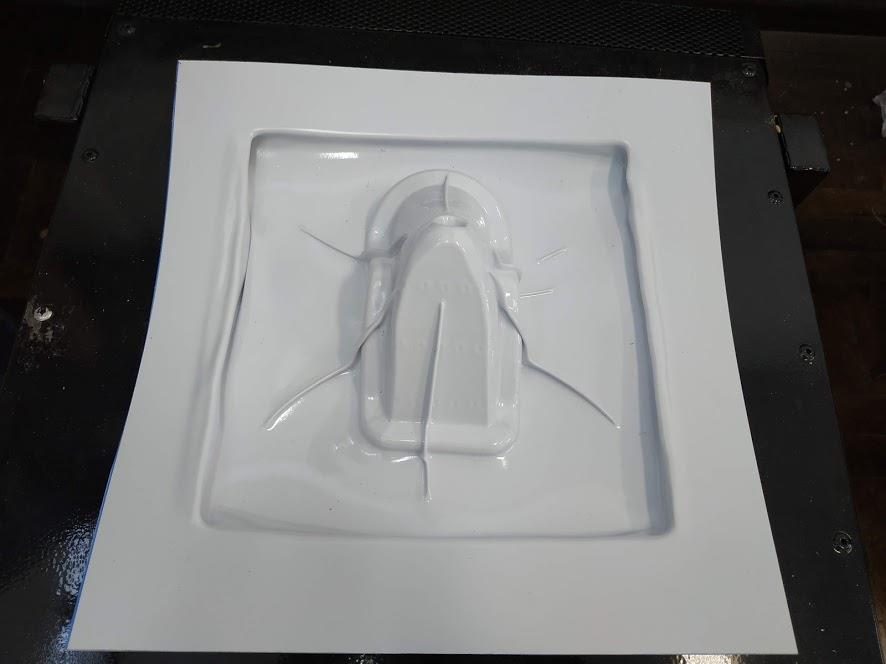
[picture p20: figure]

FONTE: DO AUTOR

Em suma, o PS foi o material que apresentou melhores resultados nos

experimentos conduzidos. Foi de fácil percepção o ponto certo de termoformagem e,

com isso, apresentou-se boa repetitividade. Assim sendo, o resultado foi uma peça

resistente, tenaz e com boa qualidade superficial.

A base da órtese foi extraída da chapa termoformada por meio de um estilete

aquecido. Foi feito, em seguida, o acabamento da peça com o uso de uma lima fina,

aparando cantos vivos e ajustando as bordas do recorte.

3.2.3. TESTE DE RESISTÊNCIA MECÂNICA

O teste de resistência mecânica teve o propósito de mensurar a máxima força

que cada conjunto material-processo é capaz de resistir. Para tanto, utilizou-se de uma

máquina universal de ensaio da EMIC, de capacidade de 10tf, disponível no laboratório

de materiais da UFPR. As bases das órteses foram posicionadas com o efetuador

diretamente acima do calcanhar e apoiada em cima de um tubo quadrado, a fim de

padronizar o teste, como visto na Figura 48.

FIGURA 48 – MÁQUINA UNIVERSAL DE ENSAIO E POSICIONAMENTO DA ÓRTESE (À DIREITA)

FONTE: DO AUTOR

Foi dado o comando à máquina para que comprimisse a uma velocidade de

20mm/min à base da órtese e gerasse um gráfico de força-deformação de cada teste

realizado.

O processo foi repetido, pelo menos, duas vezes para cada combinação

processo-material a fim de se assegurar consistência. Para caso de divergência, foi

repetido o teste mais uma vez.

Na Figura 49 são vistos os resultados do testes de resistência para diferentes

bases, da esquerda para a direita, ABS impresso na orientação vertical, PLA na

orientação horizontal e PS. Nota-se a diferença na fratura entre as orientações nas

bases impressas.

FIGURA 49 – IMAGEM DA FRATURA DOS DIFERENTES CONJUNTOS

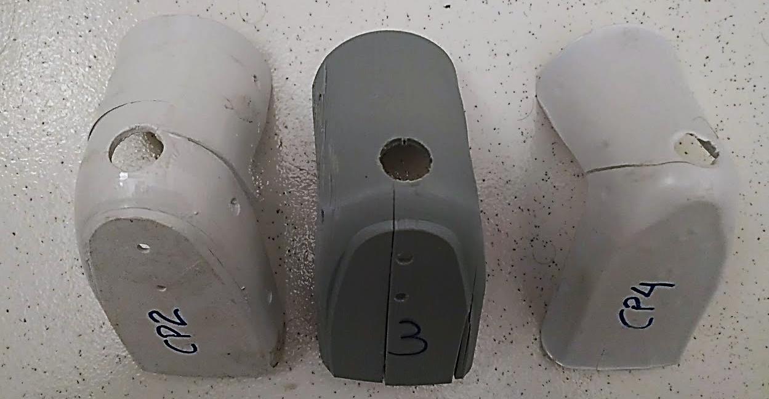
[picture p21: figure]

FONTE: DO AUTOR

### 3.3. FABRICAÇÃO DOS DEMAIS COMPONENTES

Os demais componentes foram fabricados por meio do uso de impressão 3D e

processos convencionais de fabricação como furação e corte.

Para a barra da órtese, foi comprada uma barra de alumínio de 1/8” de

espessura, ½” de largura e 6m de comprimento. A barra então foi cortada em seções

de 220mm de comprimento com uma serra manual. As seções foram, então, furadas

de acordo com o desenho técnico por meio de uma furadeira de bancada.

Tanto a argola como o regulador foram impressos em PLA através de uma

impressora 3D por extrusão. Através desse processo, foi possível fazer um grande

número desses componentes em pouco tempo. A alça foi fabricada utilizando uma

máquina de costura, velcro e um pedaço de tecido – para melhorar o conforto do

usuário.

### 3.4. MONTAGEM DA ÓRTESE

A montagem da órtese é feita rapidamente e requer poucas ferramentas e

etapas. Na Figura 50, é visto o processo de montagem da órtese dividido em seis

principais etapas.

Na etapa a), o forro recortado de uma placa de EVA é colado com cola de

sapateiro na base da órtese. Com a ajuda de um estilete e uma lima fina, são feitos os

ajustes e acabamento do conjunto (b). Em seguida são inseridos rebites para fixação

das alças (c). Colocam-se os rebites nos buracos já demarcados na geometria da base

da órtese, além disso colocam-se as argolas nas alças (d). Com o auxílio de um

rebitador manual as alças são afixadas à base da órtese (e).

Na etapa f), são instalados tanto o regulador como a barra através de um

parafuso borboleta para fácil regulagem posterior.

FIGURA 50 – PROCESSO DE MONTAGEM DA ÓRTESE

FONTE: DO AUTOR

### 4. RESULTADOS E DISCUSSÃO

O objetivo deste capítulo é estabelecer uma comparação numérica entre as

combinações processo-material fabricadas em três, de forma a comparar parâmetros

de produto e processo em uma matriz de decisão. Serão estabelecidos,

separadamente, uma análise do componente ‘base da órtese’ em 4.1, seguido por uma

análise dos resultados dos demais componentes (4.2), custo total de fabricação de uma

órtese (4.3) e, por fim, a matriz de decisão em 4.4.

### 4.1. PARÂMETROS DE TESTE DA BASE DA ÓRTESE

Como delineado no capítulo 3.1.1, as bases das órteses foram avaliadas de

acordo com seis parâmetros de testes subdivididos entre parâmetros de processo e

de produto, como visto na Figura 51.

FIGURA 51 - PARÂMETROS DE TESTE

FONTE: DO AUTOR

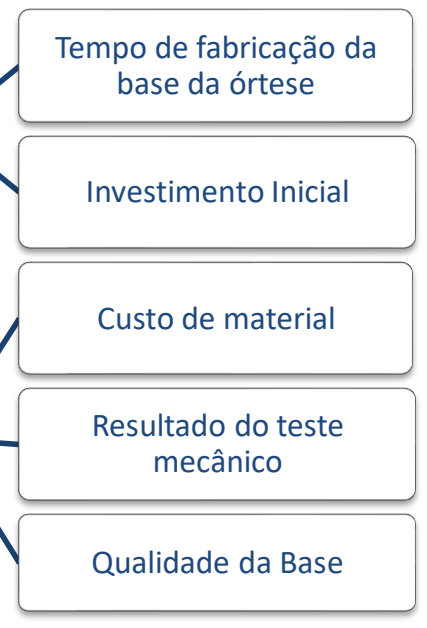
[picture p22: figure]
Tempo de fabricação da base da órtese; Investimento Inicial; Custo de material; Resultado do teste mecânico; Qualidade da Base

Para facilitar a comparação, a Tabela 14 compila todas as bases das órteses

fabricadas e identifica cada uma com um nome curto de fácil menção na coluna

“Identificação”.

### Processo

### Produto

TABELA 14 - RESUMO DAS BASES DAS ÓRTESES TESTADAS

Processo | Material | Especificação | Identificação
Termoformagem | PE | 2,0 mm de espessura | TF/PE/2,0
| PP | 2,0 mm de espessura | TF/PP/2,0
| PS | 2,0 mm de espessura | TF/PS/2,0
Manufatura Aditiva | PLA | Orientação Vertical | 3D/PLA/VER
| | Orientação Horizontal | 3D/PLA/HOR
| ABS | Orientação Vertical | 3D/ABS/VER
| | Orientação Horizontal | 3D/ABS/HOR

FONTE: DO AUTOR

4.1.1. PARÂMETROS DE PRODUTO
4.1.1.1. CUSTO DE MATERIAL

Para as bases termoformadas, na Tabela 15 se vê a lista de materiais

necessários para a fabricação, bem como fabricante e custo em R$ (Reais Brasileiros).

Foi adicionada uma coluna, Consumo/base, que diz respeito ao consumo de material

por base fabricada.

TABELA 15 - LISTA DE MATERIAIS DAS BASES TERMOFORMADAS
Produto | Especificação | Fabricante | Custo [R$/m²] | Consumo por base
PS 2,0mm | • 2x1m² • 2,0mm de espessura | ACTOS | 55,00 | 0,11 m^2
PE 2,0mm | • 2x1m² • 2,0mm de espessura | PEAGE | 41,80 | 0,11 m^2
PP 2,0mm | • 2x1m² • 2,0mm de espessura | PEAGE | 46,00 | 0,11 m^2

FONTE: DO AUTOR

Na Tabela 16 se vê, semelhantemente, a lista de materiais para as bases

fabricadas por manufatura aditiva

TABELA 16 - LISTA DE MATERIAIS DAS BASES IMPRESSAS
Produto | Especificação | Fabricante | Custo [R$] | Consumo por base
PLA | Rolo de filamento de 1 kg e diâmetro 1,75mm | BoaImpressão 3D | 115 | Vertical: 46g Horizontal: 97g
ABS | Rolo de filamento de 1 kg e diâmetro 1,75mm | Slim3D | 120 | Vertical: 46g Horizontal: 97g

FONTE: DO AUTOR

Com informações de consumo por base e custo do material, o custo do material

por base fabricada pode ser computado para cada uma das peças produzidas, como

visto na Tabela 17.

TABELA 17 – CUSTO DE MATERIAL DE UMA BASE DE ÓRTESE
Identificação | Custo/base [R$]
TF/PE/2,0 | 2,30
TF/PP/2,0 | 2,53
TF/PS/2,0 | 3,03
3D/PLA/VER | 5,29
3D/PLA/HOR | 11,16
3D/ABS/VER | 5,52
3D/ABS/HOR | 11,64

FONTE: DO AUTOR

4.1.1.2. RESULTADO DO TESTE MECÂNICO

Nesta seção serão analisados o comportamento quanto à resistência mecânica

das bases testadas, sendo avaliada numericamente por meio do limite de ruptura das

peças que romperam ou a máxima força aplicada para as peças não rompidas.

As bases termoformadas apresentaram boa tenacidade e conseguiram resistir

melhor à força aplicada, dissipando parte da energia na zona de resiliência. Dos

materiais testados, apenas o PS rompeu de forma frágil, enquanto as bases de PE e

PP não romperam até o fim de curso programado, como mostrado no gráfico sobre a

força aplicada-deslocamento disposta na .

FIGURA 52 – CURVA FORÇA-DESCOLAMENTO DAS BASES TERMOFORMADAS

FONTE: DO AUTOR

Em contrapartida, todas as bases impressas romperam fragilmente com pouca

deformação, como observado no gráfico da Figura 54. De maneira não esperada, a

base impressa verticalmente com o material PLA resistiu muito melhor ao esforço

aplicado, em torno de 783 kg de força aplicada. As outras combinações de orientação

e material resistiram menos, se comparadas a todos os outros corpos de prova.

FIGURA 53 - CURVA FORÇA-DESCOLAMENTO DAS BASES IMPRESSAS

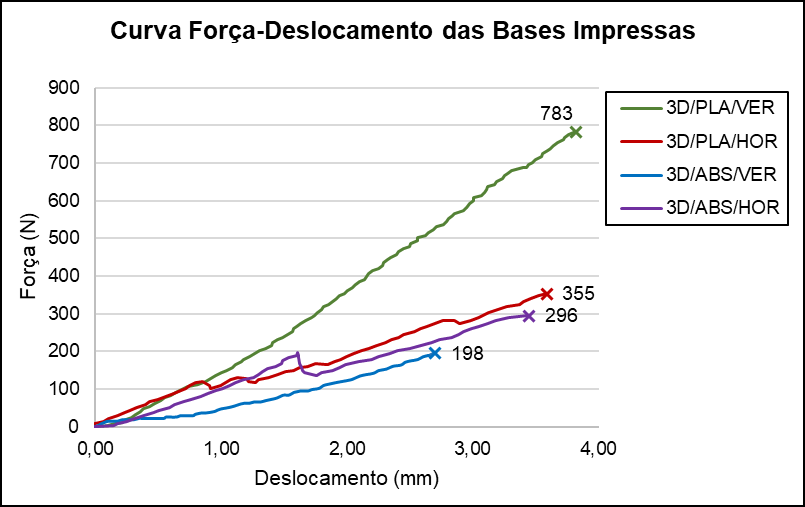
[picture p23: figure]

FONTE: DO AUTOR

Pode-se perceber a influência da qualidade da impressão no resultado, visto

que as bases impressas se mostraram com melhor acabamento e aparente melhor

resistência se comparadas com as produzidas com ABS. Isso se deve ao fato de o ABS

requerer condições especiais de impressão, tais como maior controles de temperatura,

da adesão e do resfriamento do processo. (SIMPLIFY3D, 2019)

As peças impressas apresentaram locais de fratura diferentes, sendo que as

impressas verticalmente romperam, como esperado, próximo ao furo de verificação do

calcanhar, um claro concentrador de tensão. Já as horizontalmente impressas falharam

na sola da base, indicando, possivelmente, real fragilidade na região e/ou uma interferência do aparato e estrutura do teste no resultado. É de interesse notar que,

independente da orientação, todas as bases falharam por meio do cisalhamento de

uma camada e outra que, como mencionado por Redwood (2019), é o maior ponto

fraco de uma peça impressa via extrusão.

Pode-se estabelecer, então, um comparativo entre os corpos de prova como

visto na Tabela 18.

TABELA 18 – RESULTADO TESTE MECÂNICO

Identificação | Força Máx. [N]
TF/PE/2,0 | 1039
TF/PP/2,0 | 549
TF/PS/2,0 | 421
3D/PLA/VER | 783
3D/PLA/HOR | 355
3D/ABS/VER | 296
3D/ABS/HOR | 198

FONTE: DO AUTOR

4.1.1.3. QUALIDADE DA BASE

A comparação da qualidade da base dentre as bases fabricadas se dará de

forma qualitativa e de forma a determinar se o processo/material produziu uma peça

satisfatória. Serão analisadas características como, estabilidade dimensional e

qualidade superficial em três níveis: satisfatório, não recomendável e não satisfatório.

O processo de termoformagem resultou em peças com superfície lisa e deboa

qualidade. Todavia, a necessidade de acabamento para retirada de rebarbas, muitas

vezes, criou uma variável aleatória quanto à qualidade superficial e, até mesmo,

resistência à fratura. Além disso, a presença de respiros de auxílio para o vácuo da

termoformadora geraram marcas na superfície, indicando necessidade de melhor

dimensionamento do molde.

Devido a diferença no coeficiente de retração entre os três materiais

termoformados, esses diferiram em estabilidade dimensional: o PS apresentou boa

estabilidade, mantendo-se fiel ao molde projetado; O PP apresentou pior definição para

o recorte e, ainda, baixa aderência ao molde, abrindo levemente na parte de cima; o

PE apresentou o pior desempenho se comparado com os três, apresentando alta

contração e sendo necessário ajuste do molde para compensar a retração, o que

dificultou o trabalho com o material.

As peças impressas apresentaram qualidade superficial inferior devido às

marcas de impressão características do processo (Figura 54), necessitando assim de

processos adicionais de acabamento.

FIGURA 54 – DETALHE DAS MARCAS DE IMPRESSÃO DE UMA BASE IMPRESSA COM PLA

FONTE: DO AUTOR

A base ABS impressa verticalmente apresentou, quando utilizado o vapor da

acetona, melhorou a qualidade superficial dentre as peças impressas. Quanto à

orientação, as peças impressas verticalmente, devido à ausência de suporte,

apresentaram melhor qualidade superficial.

Quando corretamente acabadas, geraram, dentre as bases analisadas, peças

termofomadas com os melhores resultados de acabamento superficial.

Na Tabela 19 há o resultado de qualidade da base, tomado como o mínimo

valor entre qualidade superficial e estabilidade dimensional. As três categorias, SAT,

NRE e NSA, são abreviações para a categoria satisfatória, não recomendável e não

satisfatória, respectivamente.

TABELA 19 – RESULTADO DA QUALIDADE DA BASE
Identificação | Qualidade Superficial | Estabilidade Dimensional | Qualidade da Base
TF/PE/2,0 | SAT | NRE | NRE
TF/PP/2,0 | SAT | NRE | NRE
TF/PS/2,0 | SAT | SAT | SAT
3D/PLA/VER | SAT | SAT | SAT
3D/PLA/HOR | NRE | SAT | NRE
3D/ABS/VER | SAT | SAT | SAT
3D/ABS/HOR | SAT | SAT | SAT

FONTE: DO AUTOR

4.1.2. PARÂMETROS DE PROCESSO
4.1.2.1. INVESTIMENTO INICIAL

Esta seção será restrita ao maquinário utilizado na confecção das bases e na

computação do valor aproximado na compra desses. Ambos os métodos de

processamento, manufatura aditiva e termoformagem, utilizaram da impressora 3D

para a produção da base. A termoformagem, no entanto, utilizou-a para a produção do

molde e, adicionalmente, uma termoformadora para confecção da órtese efetivamente.

O custo do maquinário utilizado pode ser visto na Tabela 20. O investimento foi

independente do material e dependente apenas do processo de fabricação.

TABELA 20 – MAQUINÁRIO UTILIZADO

Produto | Modelo | Custo
Impressora 3D | Ender 3 | R$ 2200
Termoformadora | FlockColor 410x410 | R$ 5000

FONTE: DO AUTOR

A termoformagem necessitou ainda do molde impresso, o qual demorou em

torno de 20 horas para ser produzido e 220 g de filamento PLA, totalizando um custo

total de energia e filamento de R$ 25,70 para confecção. Desse modo, pode-se

computar o custo do investimento inicial para cada processo, o qual foi exibido na

Tabela 21.

TABELA 21 – INVESTIMENTO INICIAL POR PROCESSO
Identificação | Custo [R$]
Termoformagem | 7226
Impressão 3D | 2200

FONTE: DO AUTOR

4.1.2.2. TEMPO DE FABRICAÇÃO E CUSTO DE ENERGIA

Nesta seção serão comparados o tempo de fabricação e o custo de energia

para a fabricação de uma base de órtese. Será feito uma lista de processo contendo

tempo, ferramenta utilizada e custo de energia para cada método de fabricação.

O custo de energia foi computado com base na potência da máquina utilizada

e o preço médio do KWh em Curitiba de R$ 0,16.

Para as bases termoformadas, constatou-se processo e tempo semelhantes

entre todos os materiais. Foi então gerada uma tabela, Tabela 22, que sumariza os

processos, ferramentas, tempo e custo de energia do processo.

TABELA 22 - LISTA DE PROCESSOS PARA TERMOFORMAGEM
Processo | Ferramenta | Tempo Total [min] | Custo de Energia [R$]
Preparar a termoformadora | Termoformadora | 6 | -
Termoformar a base da órtese | Termoformadora | 10 | 0,08
Retirar a base da órtese e esperar resfriar | | 10 | -
Recortar a base da órtese no formato correto | Estilete aquecido | 5 | -
Definir furos | Ferro de Solda | 5 | -
Aparar bordas e cantos vivos | Lima fina | 5 | -

FONTE: DO AUTOR

Para as bases impressas, parte-se do princípio da impressão da peça com uma

impressora já calibrada. Foi dividido em duas tabelas, Tabela 23 e Tabela 24, os

processos em específicos para ABS e PLA.

TABELA 23 – LISTA DE PROCESSOS PARA AS BASES IMPRESSAS EM ABS
Processo | Ferramenta | Orientação | Tempo Total [min] | Custo de Energia [R$]
Impressão da base | Impressora 3D | Vertical | 230 | 0,07
| | Horizontal | 460 | 0,14
Acabamento da peça | Vapor de Acetona | Vertical | 20 | -
| | Horizontal | 20 | -

FONTE: DO AUTOR

TABELA 24 – LISTA DE PROCESSOS PARA AS BASES IMPRESSAS EM PLA
Processo | Ferramenta | Orientação | Tempo Total [min] | Custo de Energia [R$]
Impressão da base | Impressora 3D | Vertical | 230 | 0,07
| | Horizontal | 460 | 0,14
Acabamento da peça | Lixa | Vertical | 5 | -
| | Horizontal | 15 | -

FONTE: DO AUTOR

Tem-se os valores de tempo de processamento e custo de energia

sumarizados para todas as combinações de material e processo na Tabela 25.

TABELA 25 – TEMPO TOTAL DE PROCESSAMENTO E CUSTO DE ENERGIA
Identificação | Tempo Total [min] | Custo de Energia [R$]
TF/PE/2,0 | 41 | 0,08
TF/PP/2,0 | 41 | 0,08
TF/PS/2,0 | 41 | 0,08
3D/PLA/VER | 235 | 0,07
3D/PLA/HOR | 475 | 0,14
3D/ABS/VER | 250 | 0,07
3D/ABS/HOR | 480 | 0,14

FONTE: DO AUTOR

### 4.2. DEMAIS COMPONENTES

4.2.1. CUSTO DE MATERIAL

Cada material utilizado na confecção dos demais componentes, foi

especificado e cotado de forma a incluir o custo do material não processo e, na última

coluna, uma estimativa do custo por órtese manufatura, como visto na Tabela 26.

TABELA 26 – CUSTO DE MATERIAL DOS DEMAIS COMPONENTES
Material | Especificação material não processado | Custo [R$] | Custo Estimado por Órtese [R$]
Rebite | 100 Unidades de 2,5mm | 7 | 1,20
Tala de Feltro | 100x150 mm | 11 | 4,40
Tecido | 1 m² | 10 | 0,20
Barra de Alumínio | • 1/8” espessura • 1/2” largura • 6m de comprimento | 18 | 1,50
EVA | 1 m², 2mm de espessura | 50 | 0,30
Parafusos Borboleta | Por unidade | 0,50 | 2,00
| | Total: | 9,60

FONTE: DO AUTOR

4.2.2. TEMPO DE FABRICAÇÃO, MONTAGEM E CUSTO DE ENERGIA

De modo semelhante, definiu-se um roteiro de processamento dos demais

componentes, o qual cada etapa foi avaliada em termos de tempo e custo de energia,

como visto na Tabela 27. O tempo e o custo total foram computados ao final da tabela.

TABELA 27 – TEMPO E CUSTO DE ENERGIA DOS DEMAIS COMPONENTES
Processo | Ferramenta | Tempo [min] | Custo de Energia [R$]
Cortar a barra de alumínio no tamanho correto | Serra manual | 5 | -
Furar a barra de alumínio | Furadeira de bancada 1/2HP | 20 | 0,02
Fabricar o Regulador | Impressora 3D | 30 | 0,01
Cortar Velcros | Tesoura | 20 | -
Cortar e costurar tecido no velcro | Fio e agulha | 30 | -
Colar EVA na base da órtese e aparar excesso | Cola de sapateiro | 20 | -
Rebitar velcros na base da órtese | Rebitador Manual | 28 | -
Parafusar Regulador na base da órtese | Chave Philips | 6 | -
Parafusar barra no Regulador | Chave Philips | 6 | -
| | 165 min | 0,03

FONTE: DO AUTOR

### 4.3. CUSTO E TEMPO DE FABRICAÇÃO DE UMA ÓRTESE

Para este trabalho, o tempo e o custo serão considerados separados e serão

elementos individuais na matriz de decisão. Faz sentido, logo, computar os totais de

custo e tempo de fabricação de uma órtese completa, a qual envolvem a fabricação de

duas bases e os demais componentes.

O custo total é calculado por meio da soma do custo de material, Tabela 17 e

Tabela 26, e de processamento, Tabela 25 e Tabela 27. Já o tempo total, é calculado

com a soma do tempo de processamento dos demais componentes, Tabela 27, com

os da base, Tabela 25. Por fim, pode-se gerar um gráfico com os resultados obtidos,

como visto na Figura 55 e Figura 56.

FIGURA 55 – GRÁFICO COMPARATIVO DO CUSTO TOTAL

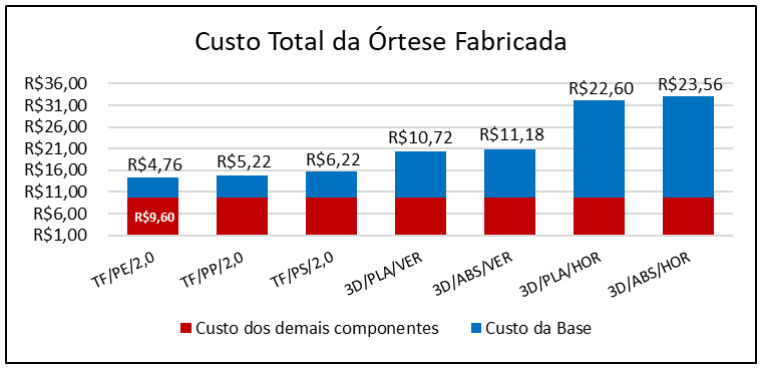
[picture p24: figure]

FONTE: DO AUTOR

FIGURA 56 - GRÁFICO COMPARATIVO DO TEMPO TOTAL EM MINUTOS

FONTE: DO AUTOR

### 4.4. MATRIZ DE DECISÃO

Os resultados obtidos nas seções 4.1, 4.2 e 4.3 foram utilizados para

elaboração de uma matriz de decisão (Tabela 28) com base nos parâmetros levantados

na Figura 51. Para cada critério, foi dado um peso de 0 a 1, com base na relevância do

critério à escolha da combinação processo-material. Além disso, buscou-se avaliar

cada ponto numericamente e de forma padronizada, sendo a pontuação 9 arbitrada

aos valores mais altos dentro do rol de dados; 6, aos valores intermediários, mas ainda satisfatórios; 3, aos valores não recomendáveis; e, por fim, 1, aos valores não

satisfatórios.

TABELA 28 – MATRIZ DE DECISÃO

Produto | Processo

Custo de
Material

Resistência
Mecânica

Qualidade
Tempo de
| Fabricação Investimento
Inicial
Ident. Peso | 0,2 | 0,2 | 0,2 | 0,2 | 0,2 | Pontos
TF/PS/2,0 | 9 | 6 | 9 | 9 | 6 | 7,8
TF/PE/2,0 | 9 | 9 | 3 | 9 | 6 | 7,2
3D/PLA/VER | 6 | 6 | 9 | 6 | 9 | 7,2
TF/PP/2,0 | 9 | 6 | 3 | 9 | 6 | 6,6
3D/ABS/VER | 6 | 3 | 9 | 6 | 9 | 6,6
3D/ABS/HOR | 3 | 1 | 9 | 3 | 9 | 5,0
3D/PLA/HOR | 3 | 3 | 3 | 3 | 9 | 4,2

FONTE: DO AUTOR

As combinações processo-material foram colocadas em ordem da pontuação,

obtida de forma ponderada. O PS termoformado mostrou-se eficaz em todos os

quesitos, enquanto o PE aparece na sequência, em função da dificuldade de obter uma

geometria com boa precisão dimensional – dificuldade de processamento. O PLA

impresso verticalmente também é uma opção adequada quando não há limitações de

tempo de produção, quesito que coloca-o atrás das órteses obtidas por

termoformagem.

Da tabela, conclui-se que as bases menos vantajosas foram as fabricadas via

impressão 3D na orientação horizontal, condição cuja peça ficou mais resistente no

local de fratura comum (próximo ao furo de inspeção de calcanhar) e mais frágil na

sola. O compromisso não se mostrou de bom custo-benefício, tanto em termos de

consumo de material, como de qualidade e resistência final, necessitando de mais pós-

processamento e tempo de fabricação.

Fato é que, para uma análise mais profunda dos materiais em questão, faz-se

necessário a otimização da geometria do molde para as bases das órteses

termoformadas, bem como a geometria da órtese em si para as bases impressas, já

que é o fator decisivo para obtenção de um bom resultado.

Outrossim, para o caso das órteses impressas em ABS, é necessário ajuste

fino para impressões bem-sucedidas. Esse fator, com certeza, dificultou a impressão

de uma peça que utilizou totalmente o potencial do material e, por fim, contribuiu para

a baixa posição deste relativo aos outros materiais.
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

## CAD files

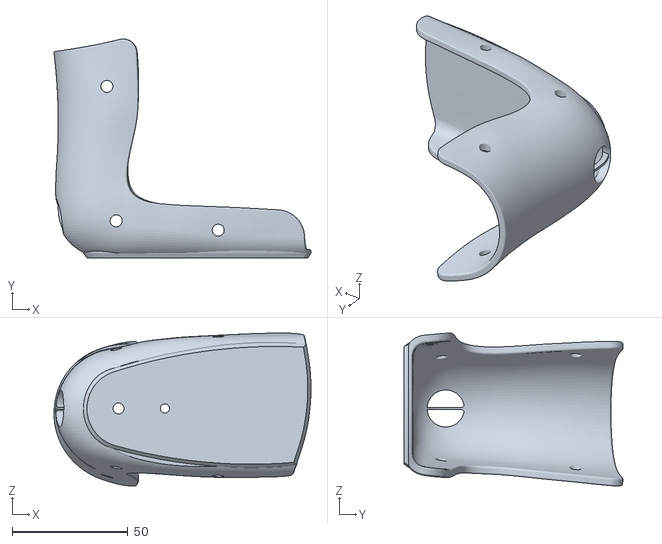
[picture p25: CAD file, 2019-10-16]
PTC/BotinhaCompleta.stl
110.8 x 94.4 x 66.0
